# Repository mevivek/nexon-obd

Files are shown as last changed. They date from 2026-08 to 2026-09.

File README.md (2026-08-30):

# Obdurate

> *ob·du·rate* — adj. unyielding; refusing to be moved.

**A read-only black box for your car.** It plugs into the OBD-II port and stays
there. It records every drive to onboard flash whether or not a phone is connected,
prints the sample rate it is actually achieving next to every reading, and never
writes anything to the car — which is a test, not a promise: the build fails if a
write service ever appears in the source.

Built on a **Seeed XIAO ESP32S3**. It hosts its own Wi-Fi access point and serves a
gauge dashboard, on-board monitor results, a UDS identifier scanner and browser-based
OTA updates. No app, no account, no internet, no cloud. Join its Wi-Fi and a page
opens; don't, and it keeps recording anyway.

**Developed and verified against a 2022 Tata Nexon 1.2 petrol (BS6).** The transport
layer, ISO-TP, the recorder, the scanner and the honesty rules are generic. The PID
lists (`PID_B1`–`PID_B4`), the ECU addresses (`ID_ECM_REQ`/`ID_TCM_REQ`), the bus
timing and the warning thresholds are that car's — a different one needs those
changed in the source, and there is no porting guide yet. If you try it on another
car, the measurements are the interesting part; open an issue.

[`docs/FINDINGS.md`](docs/FINDINGS.md) is what was measured on this one, including a
catalogue of the ways a cheap ELM327 clone lies to you.

It reaches the car two ways and picks whichever works:

| Transport | Hardware | Speed | Notes |
|---|---|---|---|
| **BLE ELM327** | none — uses a dual-mode ELM327 already in the OBD port | ~2 Hz | Works today |
| **Direct CAN** | SN65HVD230 transceiver (~₹200) | 50–100 Hz | Preferred once wired |

Everything here was verified against the actual vehicle. Where a claim is untested,
it says so.

---

## Quick start

1. Flash the firmware (see [Building](#building)).
2. Power the board — USB, or from the OBD port via a 12 V→5 V buck.
3. Join Wi-Fi **`Obdurate`** / **`changeme1234`**.
4. Open **`http://192.168.4.1`**.

That is the whole install. The dashboard is compiled into the firmware, so flashing
is all it takes — there is no second step, no laptop at the car, and no state where
the board is running but has no page to show.

You can still deploy a bundle to the filesystem with **`web/deploy.sh`**, and it
takes precedence when present. That is the edit loop: changing a line of CSS costs a
22 KB upload rather than a 1.3 MB reflash. The compiled-in copy is the floor
underneath it, so a failed or half-finished deploy falls back to the last dashboard
that was built into the firmware rather than to a stub.

| Page | What it does |
|---|---|
| `/` | Live gauges — RPM, boost, temps, trims, lambda, catalyst, driver demand |
| `/monitors` | Mode 06 on-board monitor test results, with the ECU's own limits |
| `/scan` | Discover — the autopilot, the sweep, triage and the DID watch |
| `/update` | Upload a new `.bin` over Wi-Fi |
| `/dtc` | Stored + pending fault codes as JSON |
| `/data` | Current sample as JSON, plus firmware version and active transport |
| `/trips` | Per-drive CSV logs — list, download, delete |
| `/history` | The stored trend buffer as JSON |
| `/vehicle` | What this car is and which readings it supports, as JSON |
| `/car` | Which car this board is bound to, and whether it is recording |
| `/auto` | The autopilot's phase and progress |
| `/files` | What data is on the filesystem — the list a backup is built from |
| `/file` | One data file, streamed |
| `/reset` | Erase the data, or the data and the dashboard bundle |

The header shows the running firmware version and which transport is actually live
(`can` or `ble`), so a flashed image can be confirmed at a glance.

A poll can come back with only some of its PIDs — the dashboard reads them in three
batched requests, and one batch can time out while the others answer. When that
happens the affected gauges keep showing their last reading, dimmed, and the header
reports `live · holding N`. After 2.5 s without a fresh value they fall back to `—`
rather than showing stale data indefinitely, and a held reading never raises or
sustains a warning — a value from two seconds ago cannot tell you whether the engine
is still overheating.

A single dropped poll is not reported as a fault either — the status only changes to
`no response from ECU` after five consecutive failures. Dropped replies happen, the
values are held through them, and flipping the status on each one reads as a problem
when nothing is wrong.

### Polling runs on the board, not on the page

The board samples the ECU continuously in `loop()`, one batched request per turn,
and `/data` returns the newest cached sample rather than going to the bus. Polling
therefore does not stop when you close the browser, and no request ever waits for a
poll of its own.

It did, however, wait for *someone else's*. The web server is single threaded, and
until v1.8.0 it got exactly one turn per bus exchange — up to 1.2 s on BLE, twice
that when a batch is retried. A tab switch is three requests (the document, `/time`,
and the new page's first poll), so switching pages could sit behind several seconds
of ELM327 timeouts and felt like a page load rather than a page swap.

Two things fix that, both in `bus_yield.h`:

- **The wait loops serve HTTP.** Waiting on the car is otherwise `delay(1)` on BLE
  and a 5 ms blocking receive on CAN. Both now call `webYield()` instead, which
  serves whatever is queued and reports how long it took — and the response deadline
  moves out by exactly that, because the reply is still waiting behind us either way
  (the TWAI RX queue, or the ELM notify buffer). Without the give-back, serving a
  page would eat the ECU's patience window and surface as a phantom timeout. The
  extension is capped at 3 s so one slow handler cannot hold an exchange open.
- **`loop()` drains the queue** instead of taking one request per turn, so a whole
  page load completes in a single turn.

Two guards keep that safe. `WebServer` tracks a single current client, so
`webYield()` refuses to re-enter it from inside a handler; and `obdIsoTp()` sets a
flag for the duration of an exchange so a handler reached from a yield cannot start
a second one underneath a half-finished reassembly. `/dtc` is the only handler that
touches the bus — it stands down when that flag is set, and because it runs inside
`handleClient()` and therefore cannot yield, its own timeouts are kept short.

The pages help too: the shared ~7 KB stylesheet used to be compiled into all five
documents and re-sent on every switch. It is now served once from `/ui.css` with a
version-stamped, immutable URL, and the pages carry an `ETag` so a re-visit is a
304 with no body. That is also worth ~26 KB of flash.

A sample is published after **every** batch, not after all three. The other two are
carried forward from cache while they are still fresh (3 s), so the page updates at
the bus transaction rate rather than a third of it. Batches are not polled equally
either — `b1` carries everything with a sparkline (rpm, speed, MAP, throttle, load,
coolant) and gets half the turns, because oil temperature and battery voltage do not
move fast enough to deserve equal billing:

| | Refresh |
|---|---|
| `b1` — rpm, speed, MAP, throttle, load, coolant | every 3 batches |
| `b4` — pedal, commanded throttle, torque, absolute load | every 3 batches |
| `b2` — oil, IAT, voltage, trims, fuel rate | every 6 batches |
| `b3` — lambda, catalyst, timing, run time, ambient, fuel | every 6 batches |

A batch that has not answered for three of its own polling cycles is dropped to
`null` rather than published as current, so carrying values forward can never
present a stale number as live. That window is measured, not fixed: `b2` and `b3`
come round once every four batches, so a flat timeout only holds if a batch
completes quickly. Over BLE it does not, and those two batches then expire before
their next turn — blanking twelve of the twenty rows in **All values** on every
cycle. The dashboard's own hold window scales the same way, off the observed sample
interval.

The `[alive]` serial line prints `batch=`, `cycle=` and `stale=` so all three are
visible rather than inferred.

### The board says how fast it is actually reading the car

Those numbers used to go only to the serial log, where nobody sitting in a car can
read them. They are now in `/data` as a `q` block, and on the page as the muted
trailer next to the status pill:

```
live · holding 2      1.87 Hz · b3 6.8 s
```

The rate quoted is **the board's**, not the page's. The page's fetch loop is capped
by its poll interval and throttled harder still in a backgrounded tab, so a rate
measured there can only ever be at or below the one the board is publishing — it
would understate a healthy link and could never catch a sick one. Where the two
genuinely disagree, both are shown, because that is the case worth knowing about:
the log holds samples the screen is not showing you.

This is the number every tool in this category leaves out. An ELM327 round trip puts
a cheap clone somewhere near five PIDs a second; set a tenth-of-a-second logging
interval against that and you get a log that looks complete and is mostly the
previous row repeated, with nothing anywhere to tell you which it is.

Two rules keep it honest, and they are the same ones the readings themselves follow:

- **`hz` is null, not zero, until a full pass has been timed.** A rate of zero is a
  claim that the bus is dead. Not having measured one yet is not that claim, and the
  first second of every drive is spent in that state.
- **A batch that has never answered is null, not a very large age.** Never-answered
  is usually a PID this ECU does not support; long-ago-answered is a link going bad.
  Collapsing them presents the first as the second.

The stalest batch is named only once it is past the board's own derived staleness
window — `b2` and `b3` come round once every four turns by design, so reporting the
worst one unconditionally would be a permanent complaint about nothing.

`/data` also carries a `boot` block: how this run started (`power`, `wake`, `panic`,
`brownout`, `wdt`, …), how long it has been going, and how many deep-sleep wakes
since the last cold boot. A recorder that runs unattended has to be able to answer
*what happened while I was not looking* — a board that has quietly panicked and
restarted forty times otherwise looks exactly like one that has been up all week.

**On BLE, the bus transaction rate is the limit**, and it is mostly round-trip
latency rather than the ECU. The connection interval is the floor: at a default of
40–50 ms a request and its reply cannot beat about a tenth of a second however fast
the car answers. The firmware asks for 7.5–15 ms and a 247-byte MTU, which collapses
a ~80-character reply from four or five notifications into one or two. The adapter
may refuse either, in which case nothing is worse than before. The serial log prints
`batch=NNNms` so the real cost is visible rather than guessed at.

The dashboard stops requesting while the page is off screen, and the Hz readout
counts *published samples* rather than fetches — the same cached sample can be
fetched several times and must not inflate the rate.

### Mileage

Two figures, in the glance area under boost and coolant:

- **Mileage** — the average over this drive, with the totals it came from
  (`23.6 km · 1.66 L`) underneath so the number can be checked rather than trusted.
- **Right now** — instantaneous km/L, which is what the pedal moves. Standing still
  it reads `—` and says `idling` instead, because speed ÷ nothing is not a mileage.

There is no PID for fuel economy, so it is integrated on the board from speed
(`0D`) and fuel rate (`5E`), both confirmed supported on this ECU. On the board and
not on the page, so locking the phone or closing the browser does not lose the drive.
Two rules keep it honest:

- **Both inputs or neither.** Fuel rate lives in the `b2` batch and refreshes half as
  often as speed, so it goes absent regularly. Counting the distance anyway would
  divide real kilometres by an understated litre count and report a mileage better
  than the car achieved.
- **Gaps are not driving.** An interval longer than 5 s — a BLE dropout, a scan taking
  the bus, a wake from sleep — is skipped rather than integrated at the last known
  speed. The clock still moves, so the interval after an outage is one interval, not
  the whole outage.

The average is withheld until roughly the first 0.5 km and 0.1 L. Before that it
swings by tens of km/L between polls and reads as a broken gauge.

Totals start at zero each time the board powers up, which — given the
accessory-socket supply — is exactly one drive. They also go into the trip CSV as
`trip_km` and `trip_l`, so economy over any stretch of a drive can be recovered by
differencing two rows.

One caveat worth knowing: `5E` is the ECU's injection model, not a flow meter. Trip
km/L from it typically reads a few percent optimistic against tank-to-tank. It is
excellent for comparing drives and weaker as an absolute.

### Driver demand vs. delivery

Six of the 55 PIDs the ECM supports trace one chain: **accelerator pedal (`49`/`4A`)
→ commanded throttle (`4C`) → actual throttle (`11`) → demanded torque (`61`) →
delivered torque (`62`)**, with absolute load (`43`) alongside. That is what you
asked the car for, what the ECU decided to do about it, and what the engine actually
produced — which on a small turbo is the interesting part.

Torque is reported as a percentage of the engine's reference torque (`63`), a
constant read once at startup like barometric pressure, so the newton-metre figures
are derived rather than read.

> The scalings are the J1979 ones and have **not been verified against this car** —
> `FINDINGS.md` lists the torque PID scaling as an open question precisely because it
> needs data under load. A wrong data *length* is caught (`mode01Walk` rejects the
> batch), but a wrong *scaling* would not be. Treat the numbers as provisional until
> they have been watched under load and found sane.

### On-board monitors (mode 06)

Mode 06 is the ECU's own test results: what each monitor measured, and the limits it
is judged against. `FINDINGS.md` recorded it as supported (`46 00 C0000001`) and
never explored — so `/monitors` reads it.

The value of it over `/dtc` is that a fault code only appears once a system has
already failed. Mode 06 shows how much room is left, so a catalyst drifting toward
its threshold is visible while it is still passing.

**Pass and headroom do not require knowing the units.** A test passes when its value
sits inside its own limits, and the headroom is a fraction of that window — both
unit-free. The unit-and-scaling table is long and only partly documented, so values
are shown raw with their scaling id, decoded only where the multiplier is
unambiguous. Monitor names likewise: only unambiguous J1979 ids are named, the rest
keep their raw id rather than being given a label that might be wrong.

Discovery walks the support masks (`00` → `20` → `40` …, each mask's last bit
pointing at the next), then each monitor is read one at a time. It runs only while
the page is open — monitors move over minutes, and polling them continuously would
take bus time from the values that move now.

### The DID scan runs in the background

A scan is driven by the board, so it continues if you navigate away, close the
browser, or lock the phone. Only **Stop** — or an OTA upload, which never flashes
mid-scan — ends it.

While it runs the scanner takes most of the bus, but not all of it — the sampler
still gets one batch every two seconds, so live values keep moving slowly rather
than freezing. That costs roughly 15 % of scan throughput, which is a good trade
against a dashboard that is dead for the length of a sweep.

The Live page shows the sweep's progress with counts as well as a percentage — a
full pass is 65,536 requests, so a percentage alone rounds to zero for a long time
and reads as stuck — and the scanner page estimates the time remaining.

Scanning is time-boxed to 250 ms per turn rather than a fixed identifier count. A
count behaves wildly differently per transport — 40 identifiers is about a second on
CAN but roughly 22 s over BLE, during which nothing answers the web server and the
board appears hung.

### Watching identifiers to find out what they hold

A sweep finds identifiers that answer. It cannot say what any of them contain — the
manufacturer-specific block (ISO 14229-1 hands `0100`–`A5FF` to the manufacturer)
comes back as one or two raw bytes with no name, unit or scaling, and that lives in
an ODX database nobody outside the supplier has.

What you can do is correlate. `/watch` reads up to **8** chosen identifiers
continuously and shows them next to rpm, speed, coolant, intake, load and throttle,
each with a sparkline. Blip the throttle and an rpm-linked value gives itself away.
The ones the scanner found are offered as checkboxes, so there is no copying hex
between pages.

**Coming from a build before 1.7.0:** those sweeps kept their hits in RAM only —
nothing was written to flash — so an updated board comes up with an empty picker
even though the sweep happened. The `did_hits.csv` you exported is the only copy,
and the picker loads it directly: choose the file and the identifiers appear as
checkboxes, merged with anything the board found itself. It is parsed in the
browser and kept in `localStorage`; nothing is uploaded, and there is no endpoint
that would make a browser a second source of truth for what the board found.

The same readings become extra columns on the trip CSV — two per identifier: the
bytes decoded big-endian, and the raw bytes beside them. Two bytes might equally be
one 16-bit value or two 8-bit ones and nothing in the reply says which, so the
decode is a convenience and the raw column is the record. An identifier that has
stopped answering writes **empty** cells rather than zeros, the same rule the PID
columns already follow: a missing reading must not correlate as a value of nought.

Changing the set **rotates the CSV**. Columns are fixed when a file is opened, and
shifting them halfway down one is worse than having two files. Re-applying an
identical set is not a change, so pressing Apply twice does not litter the partition.

The cost is real and the page states it. Every watched identifier is one more bus
exchange, and BLE affords about six a second in total — eight at the default one per
second is roughly a sixth of the budget. Watching **pauses entirely while a sweep is
running**; a sweep is already hours long and shares the bus with the sampler, and a
third claimant would do both jobs badly.

This gives correlation, not meaning. It will tell you `1002` tracks coolant; the
offset and scale come from fitting the logged column against the PID afterwards.
Service `0x22` is still a read — only the identifier varies, never the service.

### Trip logs

A CSV row a second while the ECU is answering, written to the 1.5 MB filesystem
partition. Twenty-six columns — wall-clock time and uptime, then twenty-four
readings — and empty cells rather than zeros where a value was not read, so a gap is
a gap and not a reading of nought.

> **This did not work until v1.12.0.** `tripTick()` was written, documented here,
> and never called from anywhere. `/trips/list` returned an empty array on every
> board that has ever run this firmware, and the DID-correlation workflow described
> below — the route this project has for decoding the `10xx` block — has never
> produced a row. If you flashed anything before v1.12.0, there are no trip logs to
> recover; there never were any.

Roughly half a megabyte an hour bare, so the partition holds two to three hours, and
the oldest trip is deleted automatically when space runs short. Watched identifiers
change that materially: each one adds two columns and up to 26 bytes to every row,
so a full set of eight is closer to **1.3 MB an hour — about one hour of capacity**.
The columns are chosen when a file is opened, so the cost is fixed for that file.

LittleFS rather than SPIFFS: the board loses power the instant the ignition goes
off, mid-write as often as not, and LittleFS is built to survive exactly that.

A full partition is the ordinary end state of a device left in a car, not an edge
case. Logging stops rather than pretending: `tripEnsureSpace()` reports whether it
managed to reach the free-space floor, a file is not opened when it did not, and the
row terminator is checked so a write that did not land is seen. Without those, a
failed write left `size()` where it was, the rotation that would have freed space
never fired again, and logging stopped for the rest of the drive in silence.

The clock comes from whichever page you open, so a drive that starts before you open
one has an unset clock for its first rows. Each file's header records whether the
clock was set rather than implying a timestamp it does not have.

### Scans survive being switched off

A sweep is tens of thousands of requests — the better part of a day over BLE — so it
has to outlast the car being switched off. Position goes to NVS as it runs, hits are
appended to the filesystem the moment they are found, and an interrupted sweep
resumes on the next boot rather than starting over.

It also stops sweeping when the ECU stops answering. **A timeout and a negative
response mean opposite things:** a negative response is the ECU saying "no such
identifier", which is a result worth recording; a timeout is no answer at all. After
25 consecutive timeouts the sweep holds its position and probes every few seconds
until the car answers again.

Without that, switching the ignition off mid-sweep would record thousands of
identifiers as "no response" — turning an unswept range into one that looks swept
and empty. That is the same class of silent wrong answer as the `ATCRA` bug in
[FINDINGS](docs/FINDINGS.md), and it matters here because the whole value of the
sweep is its negative result.

### Trend history

The board keeps one hour of RPM, speed, boost and coolant at 6-second resolution and
serves it at `/history`, so the sparklines have shape the moment the page loads
instead of starting flat.

It survives restarts, which matters more than it sounds — the board restarts
constantly in normal use, so history in ordinary RAM would be wiped every time you
got back in the car. How it restarts depends on how it is powered: from the
accessory socket the power is simply cut when the car goes off; from the
permanently-live OBD pin 16 it deep-sleeps after 10 idle minutes and wakes every
30 s, running `setup()` each time.

| Store | Survives | Written |
|---|---|---|
| RTC slow memory (4.8 KB) | deep sleep | every 6 s, free |
| NVS (flash) | power loss | every 6 s (each new sample), and before sleeping |

Which store matters depends on how the board is powered. Wired to the ignition it
simply loses power when the car goes off — RTC memory does not survive that, and the
save on the way into deep sleep never runs, so the periodic flash write is the only
thing keeping a trip's history. It runs on every new sample, so switching off costs
at most 6 seconds. Wired to the permanently-live pin 16 the board deep-sleeps
instead, and RTC memory carries the buffer across for free.

Flushing that often is only affordable because a flush writes **the 400-byte chunk
that moved**, not the whole 4800-byte ring. Rewriting all of it — which is what it
did until v1.3.0 — costs somewhere over a flash sector erase per save, so shortening
the interval that way would have burned through NVS endurance in a couple of years.
Chunked, ten times the flush rate still churns less flash than the old
sixty-second full-buffer write did.

### What car is this

Every other part of this firmware is written against one vehicle. The PID batches
are the set a Nexon replies to, the DID register is 214 verdicts about a Nexon's
ECU, and the dashboard draws tiles for readings that car publishes. Plugged into
anything else, none of that announces itself — the tiles that cannot be filled read
blank, which is indistinguishable from a car that is simply not answering yet.

So the board asks, once per boot: the mode 01 support bitmaps block by block, then
mode 09 for the VIN, the calibration id and its checksum, then one probe at the
transmission's responder id. `/vehicle` reports the answers, including which of the
PIDs the sampler actually polls this car supports.

This is **discovery, not adaptation**. The sampler still asks for the same PID set
and an unsupported reading still comes back absent — it is now labelled
absent-because-unsupported rather than absent-because-silent, which is the whole
difference between a dashboard that is broken and one that is honest. Adapting the
batches at runtime needs a vehicle-profile format, and designing that against a
sample of one car would be designing it blind.

Three states throughout, never two. A support block whose bitmap never arrived reads
*unknown*, not *no*; a mode 09 refusal is a fact about the car, a timeout is a fact
about the last few seconds. Nothing answering at the second responder id is reported
as exactly that, never as "no second ECU" — a module that is not fitted and one that
is not awake produce the same nothing on a CAN bus.

### Backup, restore, and the check in between

A sweep is over half an hour on CAN and the better part of a day over BLE, the
register behind it takes drives to build, and the trip logs are the drives
themselves. All of it lives on a 1.5 MB partition inside a device that gets
unplugged, reflashed and left in a hot car.

The Board page takes the lot off as a ZIP, puts it back, and clears it. The archive
is assembled **in the browser** — the board has one core and a car to poll while it
serves you, so it offers a list (`/files`), a reader (`/file`) and a writer
(`/file/put`) and the page does the work. Entries are STORED, never deflated, so the
file opens with any unzip tool and the reader that puts it back is a header walk
rather than an inflater shipped into a 300 KB budget.

The reason any of this needs the section above: `didmap.csv` is 214 verdicts about
one specific engine and nothing inside it says which. Restored onto a different car
it would not fail — it would attach, silently, and every conclusion drawn from it
afterwards would be about the wrong engine. So a backup carries a manifest holding a
hash of the VIN and calibration id, and a restore compares it. A mismatch is refused
outright with no way past it. A backup or a board with no identity at all is the
ordinary state of a car that has not been driven yet, and that is put to the person
as a question rather than answered on their behalf.

The manifest carries the hash, not the VIN. It answers the only question the archive
is asked exactly as well, and a backup is a file that gets copied to a phone and a
laptop.

### One board, one car

Everything this board accumulates is about a particular vehicle — the sweep's hits
are that car's identifier space, the register is verdicts about that car's ECU, the
trip logs are that car's drives. None of it carries a vehicle in the record itself,
so mixing two cars does not produce a detectable error. It produces a file that is
quietly wrong forever.

So the binding is explicit. The board stores the key of the car it belongs to, and
in a car that is **provably** a different one it records nothing: no sweep, no
triage, no trip log, no correlation. The live dashboard keeps working, because it
reads what the car is doing now and persists none of it — and a board showing a
blank screen in the wrong car would be useless at exactly the moment somebody wants
to glance at a temperature. It also bounds the filesystem, which is the other half
of the reason: a 1.5 MB partition holding one car's data is comfortable and two
cars' is not.

A banner then offers the only choice that is anyone's to make: **onboard this car**,
which erases the previous one's data and starts again, or **keep the other car**,
which leaves the binding alone and gives this one live readings only.

Three answers, not two, and the middle one is the important one. A key exists only
once mode 09 has answered, so "the keys differ" and "there is no key" are completely
different facts and only the first stops anything. Reading absence as a mismatch
would silently disable recording on every car that declines mode 09, and the
symptom — a board that runs, shows live data and never writes a trip log — is one
nobody would diagnose.

### The autopilot

The investigation used to be four phases and three decisions, hours apart, with the
last step done by hand in a spreadsheet. Nobody chooses differently at any of those
points, which is what makes it automatable — and the phases outlast anyone's
attention, so a prompt between them is one that gets missed.

Started once, the board sweeps the identifier space, triages the hits to find which
move, then watches the ones that move eight at a time, fitting each against the live
readings. It advances on its own and keeps its phase in NVS, because the ignition
going off is a power cut and this pipeline is measured in drives:

- **Sweep** — about 30 minutes on CAN, the better part of a day over BLE.
- **Sweep (TCM)** — the same again at the transmission controller, which is a
  separate identifier space at a separate address. Only when discovery's probe at
  0x7E9 actually answered: a sweep of an ECU that is not there does not fail, it
  stalls, and holding position — right for a sweep — would hold the pipeline for
  good. Silence there is reported as "not swept, and here is why", never as proof
  there is no module.
- **Triage** — about an hour of engine-on. This adapter answers roughly half of what
  it is asked, so ten clean reads of every hit needs about twenty passes.
- **Watch** — one drive per eight identifiers, so eight or nine drives for a
  register the size of this car's.

The watch set rotates between drives and never during one: changing it bumps the
watch generation, which rotates the trip CSV, and rotating mid-drive would turn one
drive into a pile of short files.

Two things it will not do. A sweep that finds nothing is a **conclusion** — this ECU
does not answer service 0x22 — not a reason to sweep again. And a car the board is
not bound to **holds** the pipeline rather than ending it, so an afternoon in
somebody else's car does not cost the drives already spent.

### The board does the fitting now

Watching logs an identifier beside rpm and coolant; something then has to fit one
against the other. That was the only step still done by a person, it is the same
arithmetic every time, and it is why a board that had collected everything needed to
answer "what is 1002" still could not say anything about it.

A Pearson correlation is six running sums. Eight watched identifiers against six
reference signals is forty-eight of them, which is nothing on an ESP32, and the best
fit goes into the register as three new columns — so `/didmap.csv` now carries
`tracks,r,samples` on the end. They are appended rather than inserted so a register
written by an older firmware still loads; that file is what a restore puts back, and
a format that rejected last month's backup would throw away hours of bus time to
gain a column.

**It says "tracks", never "is".** Everything under a bonnet correlates with
everything else — oil temperature tracks coolant almost perfectly, and both track
runtime after a cold start — so a strong fit narrows the field rather than settling
it. r is also unchanged by offset and scale, so a perfect correlation still leaves
the units unknown. Naming an identifier stays a human act, which is why
`DID_IDENTIFIED` outranks every machine verdict.

A pair is only counted when **both** sides are present. This adapter drops roughly
half of what it is asked, and folding a missing reply in as a zero would fit the
dropout pattern rather than the car — convincingly.

### Being left in the car

The board deep-sleeps after ten minutes with no ECU response. That timer answers
*the car is off*, which is the ordinary case, and it does not answer *the battery is
going flat* — the two come apart exactly where it matters. An ECU that keeps
answering with the engine stopped (ignition on at the roadside, a long session
parked, a module that stays awake) resets the idle timer on every reply, so the
ten-minute guard never arms and the board keeps drawing from a battery nothing is
charging.

So there is a second floor under it: **below 11.8 V for thirty continuous seconds
with the engine stopped, the board shuts down.** A lead-acid battery at rest sits
near 12.6 V; 11.8 V is roughly a quarter charged and about where a cold start stops
being a certainty.

Three things keep it from firing when it should not, and each is tested:

- **Cranking does not trip it.** The rail sits at nine volts and below for about a
  second while the starter turns, which is the one moment the reading is low and
  switching off would be exactly wrong. Thirty continuous seconds is well past any
  crank, and past the sag from a fan or a heated screen starting up.
- **A turning engine is proof something is charging**, whatever the rail reads, so
  any rpm above 300 breaks the run outright.
- **An absent reading is never a low reading.** An unread voltage and an unknown
  engine state both break the run rather than counting toward it, and the guard is
  fed the sample only while it is fresh — a voltage from ten minutes ago must not
  switch the board off now. That is the idle timer's job and it is already running.

> **The idle draw has not been measured.** The guard above bounds the worst case at
> a battery that can still start the car, but no number for what this board actually
> pulls — asleep, or awake with the AP up — has been put on a meter yet. Until it
> has, treat the advice below about unplugging a parked car as applying to the board
> as much as to the adapter.

The onboard LED encodes state, which matters when the board is hidden under the dash:

- **slow blink (1 Hz)** — alive, Wi-Fi up, ECU not answering
- **fast blink (5 Hz)** — talking to the ECU
- **double-blink** — DID scan running

---

## Frontend

The dashboard is a Preact app under `web/`, built with Vite and served off the
board's filesystem. It is not compiled into the firmware.

```bash
npm --prefix web install
npm --prefix web test          # 206 checks
web/deploy.sh                  # build, then upload to 192.168.4.1
```

**It ships two ways, and the order matters.** The built bundle is compiled into the
firmware, so flashing the board is the whole install. A bundle uploaded to LittleFS
overrides it, which is what keeps the edit loop cheap: changing a line of CSS costs a
27 KB upload, not a 1.3 MB reflash.

That is not a return to what v1.11.0 removed. What went then was hand-written
JavaScript inside C++ raw string literals — no bundler, no packages, no source maps,
and nothing in the build that ever parsed it, so a typo shipped and surfaced as a
dead dashboard in the car. All of that stays gone. `web/scripts/embed.mjs` reads the
output of the ordinary Vite build, after the ordinary Vitest suite, and turns the
finished gzipped bytes into a byte array. Nothing about how the frontend is written,
bundled or tested changes — only where a copy of the result ends up.

What it buys is that there is no state where the board runs and has no page. Someone
who flashes through [`docs/flash/`](docs/flash/) has a working dashboard the moment
it boots, rather than needing a laptop, the board's Wi-Fi and `web/deploy.sh` first.

**Why the board and not a web host.** The access point has no internet, so a phone
joined to it cannot load a page from anywhere else. Chrome 142 relaxed mixed-content
checks for literal private IPs behind a permission prompt, so an HTTPS page *can*
now reach `192.168.4.1` — but only on Chrome, only if the permission was granted
before you got in the car, and Android 17 adds a second prompt on top. Serving from
the board has none of those conditions: no mixed content, no CORS, no permissions, no
internet, any browser.

**Deploying cannot brick it**, and the floor is higher than it was. `/ui` is compiled
into flash, so the page that fixes a bad deploy never depends on the deploy having
worked. If no bundle is installed, or the upload was interrupted, `/` falls back to
the dashboard compiled into the firmware — the whole thing, not a four-value stub.
Trip logging, the DID sweep and the history buffer are the board's work and run
regardless of what the browser can see.

| | |
|---|---|
| Bundle | 27 KB gzipped, **one file**, compiled in and overridable |
| Budget | 300 KB, capped in the build and enforced by the firmware on upload |
| Shares with | trip logs — 300 KB is about 35 minutes of recording capacity |

The build inlines the script and stylesheet into `index.html`, so a deploy is a
single `index.html.gz`. That is not for the bytes — one gzip stream over the lot is
barely smaller than three — but for how it gets installed: the board is updated from
a phone standing next to a car, and a firmware update is one `.bin`, so the frontend
should cost no more than that.

The firmware serves it with `Content-Encoding: gzip` and `no-cache`, so a new deploy
is always picked up, and answers `/monitors`, `/trips`, `/watch` and `/scan` as
redirects into the app's routes so old bookmarks keep working.

**The `/data` contract** is declared in `contract/data.json` and checked from both
ends — the firmware test asserts it against `handleData()` in both directions, so a
field renamed on one side fails the build instead of blanking a gauge on the road.

---

## Hardware

### Option A — no extra parts

Uses a dual-mode ELM327 clone over **BLE GATT**. The ESP32-S3 has **no Bluetooth Classic
radio**, so it cannot use the usual SPP path — but many ELM327 clones also expose a BLE
interface, and this firmware drives that.

Check yours advertises service `FFF0`. On the unit this was built against:

```
BLE address 81:23:45:67:89:BA   name "OBDBLE"
  SERVICE 0000fff0
    CHAR 0000fff1  Read, Notify               <- responses
    CHAR 0000fff2  WriteWithoutResponse, Write <- commands
```

Note the BLE address is the Classic MAC with the top bit of octet 0 set
(`01:…` → `81:…`). Set `ELM_BLE_ADDR` in `elm_ble.h` to match your adapter.

### Option B — direct CAN (recommended)

| Part | Notes |
|---|---|
| **SN65HVD230** transceiver | **3.3 V part.** Do *not* use TJA1050 or MCP2551 — they are 5 V logic and will damage the ESP32's RX pin |
| 12 V→5 V buck (MP1584/LM2596) | Set output to 5 V *before* connecting the board |
| OBD-II male pigtail | |

**Wiring**

| XIAO ESP32S3 | SN65HVD230 |
|---|---|
| D1 (GPIO2) | CTX / D |
| D2 (GPIO3) | CRX / R |
| 3V3 | VCC |
| GND | GND |

| SN65HVD230 | OBD-II pin |
|---|---|
| CANH | 6 |
| CANL | 14 |

Power from OBD pin 16 (+12 V) and pin 4/5 (GND) into the buck, 5 V out to the XIAO's `5V` pad.

> **Remove the 120 Ω termination resistor** on the transceiver breakout. The vehicle bus
> is already terminated at both ends; a third terminator causes bus errors.

> **OBD pin 16 is permanently live**, so anything plugged into the OBD port draws
> from the battery whether the car is running or not. That includes a BLE ELM327
> adapter — clones typically pull 20–50 mA, roughly 0.5–1 Ah a day — so unplug the
> adapter if the car is parked for more than a few days. This applies to the adapter
> even when the board itself is powered from the accessory socket and switches off
> with the ignition; the two are independent.
>
> The board deep-sleeps after 10 minutes with no ECU response, which protects the
> battery only if the board is itself wired to a permanently-live supply.

---

## Building

```bash
firmware/build.sh              # tests, then compile
firmware/build.sh --upload     # …then flash over USB (PORT=… to pick the port)
```

If you already have `arduino-cli` with the ESP32 core — an Arduino IDE install counts
— it uses that and downloads nothing. Only on a machine with neither does it install a
private copy into `firmware/.toolchain/` (~6 GB unpacked, several minutes), and that
install writes nothing outside the repo, so deleting the directory undoes it
completely. `OBDURATE_ISOLATED=1` forces the private toolchain, which is what CI
wants: a build that depends on whatever happens to be on the machine is not
reproducible.

The upload port is guessed from `arduino-cli board list`, taking only a port it
recognises as an ESP32 — Windows has several Bluetooth serial ports that must not be
flashed at. Override with `PORT=COM3` or `PORT=/dev/ttyACM0`.

> Building needs `g++`, `python3` and `node` on `PATH` for the host tests, which run
> before the compile. Contributor notes for the development machine — including where
> its compiler lives and how to read the board's serial log on Windows — are in
> [`CLAUDE.md`](CLAUDE.md).

The output you want is **`firmware/build/Obdurate-v<version>.bin`** — the app image,
which is what `/update` takes. The version comes from
[`firmware/Obdurate/version.h`](firmware/Obdurate/version.h); bump it there and the
filename, the dashboard header and the serial banner all follow.
`Obdurate.ino.merged.bin` in the same directory is a full-flash image for USB
recovery; feeding *that* to `/update` will not work.

By hand, if you would rather not use the script:

```bash
arduino-cli config add board_manager.additional_urls \
  https://espressif.github.io/arduino-esp32/package_esp32_index.json
arduino-cli core update-index
arduino-cli core install esp32:esp32

arduino-cli compile --fqbn esp32:esp32:XIAO_ESP32S3 --output-dir build firmware/Obdurate
arduino-cli upload -p COM3 --fqbn esp32:esp32:XIAO_ESP32S3 firmware/Obdurate
```

Current size: **1.26 MB flash (37 % of `app0`)**, 49 KB RAM (15 %), plus 4.8 KB of
RTC slow memory for the trend buffer. The frontend is no longer part of that: it is
a 22 KB gzipped bundle on the filesystem, and moving it out returned 47 KB of flash.

The default `default_8MB` partition already provides `ota_0` + `ota_1` at 3.19 MB each,
so OTA works without changing the partition scheme.

### Tests

```bash
firmware/test/run.sh          # needs g++, python3 and node — no ESP32 core, no board
```

The ISO-TP layer and the mode-01 batch poller are extracted straight out of
`Obdurate.ino` and compiled against fake TWAI and ELM327 shims, so frame sequences
that are impractical to stage against a real car — a dropped consecutive frame, a
reordered sequence number, a reply that stops halfway — are covered. The same shims
stand in for the web server, so the deadline give-back described above is tested for
the two properties that make it safe: a silent ECU is still reported silent, and the
extension is bounded. Everything else the sketch
can be asked about without a board — the `/data` contract, the routing, the caching
headers, the DID watch wiring, the trip columns, the history constants — is asserted
against the source under node.

The frontend has its own suite, `npm --prefix web test`: 382 checks over the
hold-last-value merge, the warning-flag gating, the rate tracker, the mileage
readouts and each page's logic, run against the modules that implement them. That is
the point of the split — those used to be JavaScript inside C++ raw string literals,
which nothing in the build ever parsed, so a typo shipped and surfaced as a dead
dashboard in the car.

The "All values" table is checked in a real browser instead, because the node
harness structurally cannot check it: its fake DOM creates any element asked for by
id, so a table whose cells are built once and then addressed by id passes whether or
not those ids line up with the rows — the whole suite goes green with every value
shown against the wrong PID. `test_table.mjs` renders the built bundle and
the built bundle, drives it through a full sample, a partial poll and a recovery,
and asserts that row *i* shows the value of the PID row *i* names. It skips itself, without failing, where
Playwright is not installed.

To look at the pages without flashing anything:

```bash
node firmware/test/shots.mjs out/     # needs playwright + chromium
```

It serves the real pages against a mock `/data` and screenshots them at phone and
tablet widths across four states — cruising, a partial poll, warnings, and ignition
off. The partial-poll shot is the one worth checking after any change to the polling
code, since that is the state that used to blank the dashboard.

### OTA

Run `firmware/build.sh`, join `Obdurate`, and upload
`firmware/build/Obdurate-v<version>.bin` at `http://192.168.4.1/update`. The header
shows the new version once it reboots, which is how you confirm the flash took.

The board runs from `app0`; an upload streams into `app1`; `otadata` only flips once
`Update.end()` verifies the image, then it reboots. An interrupted or corrupt upload never
touches `otadata`, so **a failed OTA cannot brick the board** — it reboots into the
firmware it was already running.

So the loop is: build locally → copy the `.bin` to your phone → join the board's Wi-Fi →
upload at `/update`. No dev machine needed at the car, only to produce the image.

> **CI is not in use.** [`ci/build.yml`](ci/build.yml) is kept current — it runs the host
> tests and compiles the firmware — but it is parked outside `.github/workflows/`, since
> pushing there needs the `workflow` OAuth scope this repo's token lacks. Build locally
> with `firmware/build.sh`. To enable CI later:
>
> ```bash
> gh auth refresh -h github.com -s workflow
> git mv ci/build.yml .github/workflows/build.yml
> git commit -m "Enable CI" && git push
> ```

---

## Before you use this

Change the access point credentials in `Obdurate.ino` — they are placeholders, and the
board is an open target on any network it creates:

```cpp
static const char *AP_SSID = "Obdurate";
static const char *AP_PASS = "changeme1234";   // >= 8 chars
```

`/update` has **no authentication**. Anyone who can join the AP can flash the board, so a
strong `AP_PASS` is the only thing protecting it.

Set `ELM_BLE_ADDR` in `elm_ble.h` to your own adapter's BLE address — the one committed
here is from the unit this was developed against.

---

## Architecture

```
                    ┌───────────────────────────┐
  phone ──Wi-Fi AP──┤  XIAO ESP32S3             │
                    │   WebServer :80           │
                    │   bundle (LittleFS) + API │
                    │                           │
                    │   obdIsoTp() dispatcher   │
                    │      ├── canIsoTp  (TWAI) ├──SN65HVD230──┐
                    │      └── bleIsoTp  (GATT) ├──BLE──ELM327─┤ OBD-II
                    └───────────────────────────┘              │  pins 6/14
                                                               ▼
                                                            vehicle CAN
```

Both transports implement the same contract — request bytes in, reassembled ISO-TP
payload out — so mode 01, mode 03 and UDS `0x22` are written once and work on either.

`chooseTransport()` prefers CAN when the transceiver answers, else falls back to BLE.
While the ECU is silent it re-evaluates on a backoff — 2 s, then 4, 8, 16, settling
at 20 — resetting to impatient as soon as data arrives.

That matters when the adapter outlives the board, which is the usual split: the OBD
port is always live but an accessory-socket supply is not. Every start then meets an
ELM327 that may still be holding the BLE link to a board that vanished without
disconnecting, so the first connect can fail for a reason that clears itself within
seconds. A flat retry interval meant a dead dashboard for that whole interval at
every ignition.

---

## Safety

This firmware is **read-only by design**, and since v1.12.0 that is a test rather
than a promise. Every request buffer in the sketch is found from its call sites, its
service byte read out of the source, and checked against the list of reads. Adding a
write service fails the build and names it.

What it actually sends, as the check reports it:

| Service | |
|---|---|
| `0x01` | mode 01 live data |
| `0x03` | mode 03 stored fault codes |
| `0x06` | mode 06 on-board monitor results |
| `0x22` | UDS ReadDataByIdentifier |

plus ISO-TP flow control. It never sends:

| Service | Why not |
|---|---|
| `0x2E` WriteDataByIdentifier | writes ECU memory |
| `0x31` RoutineControl | triggers actuators |
| `0x11` ECUReset | resets a live ECU |
| `0x10` DiagnosticSessionControl | changes ECU state |
| `0x27` SecurityAccess | unlocks protected functions |
| `0x14` ClearDiagnosticInformation | erases the car's own record |

> This table used to claim mode 07 (pending codes) and mode 09 (vehicle info) as
> well. Neither is sent — there is no `0x07` or `0x09` request anywhere in the
> sketch, and the sketch's own header comment made the same claim. Writing the check
> is what found it. Both are reads and both are worth having; they are simply not
> implemented yet.

A request is also bounded now. An ISO-TP single frame is one PCI byte and seven of
payload, and the request was copied into an eight-byte stack buffer with nothing
checking the length. The largest caller in the tree — the mode 01 batch, six PIDs
plus the mode byte — passes exactly seven. At the limit, with nothing spare: a
seventh PID in a batch, or packing two identifiers into one `0x22` request to get
the obvious threefold throughput win, would have written past the frame and said
nothing about it.

Run scans **parked**. Reading is safe; a stalled request while driving is not worth the risk.

---

## Documentation

- **[docs/FINDINGS.md](docs/FINDINGS.md)** — what this specific car exposes, and the
  adapter quirks that cost hours to discover
- **[docs/TOOLS.md](docs/TOOLS.md)** — the PowerShell scripts in `tools/`

## Licence

MIT — see [LICENSE](LICENSE).

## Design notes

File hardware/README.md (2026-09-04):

# Obdurate Rev A — hardware

One carrier board, 40 × 40 mm, four layers, in a clear Minitools case whose
OBD-II connector is a matched module from the same family. It carries the CAN
transceiver, the 12 V power chain and the test points; the MCU arrives as a
module, and there are **two variants of which module**.

**There is no schematic or layout here yet, and no Gerbers.** What is here is
everything a schematic would carry, in formats that can be checked: the netlist,
the placement, the board outline, the bill of materials and the fab settings.

Everything is a *design*, not a *measurement*. Nothing has been fabricated. The
prototype that proved the firmware is a XIAO ESP32S3 on flying leads to an
SN65HVD230 breakout — which is exactly what the `-xiao` variant turns into a board.

---

## Two variants, one circuit

| | `-xiao` | `-wroom` |
|---|---|---|
| Module | Seeed XIAO ESP32S3, 21 × 17.5 mm | ESP32-S3-WROOM-1-N8R8, 18 × 25.5 mm |
| Buck output | **5 V** into the XIAO's 5V pad; its LDO makes 3.3 V | **3.3 V** directly |
| USB | on the module | J2 on the board, **0.5 mm pitch** |
| 3.3 V regulator | on the module | U4 + D3 OR diode on the board |
| Status LED | **on the module** — its onboard LED *is* GPIO21 | LED1 + R1 on the board |
| Boot / reset | buttons on the module | R3, R4, C7 on the board |
| Antenna | U.FL flying part, positioned in the case | PCB antenna, needs a board keepout |
| Finest pitch | 1.27 mm (SOIC-8) | 0.5 mm (USB-C) |
| Parts | ~25 | ~38 |
| Module cost | ~$7.00 | $3.20 |

**Rev A is `-xiao`.** Rev A's job is Gate 1 — five units surviving a week in a
car — not hitting a cost target, and the XIAO removes twelve parts, the finest
pitch on the board, the antenna keepout and two open questions. It is also what
the firmware already runs on, so nothing about the software is new.

**`-wroom` is the volume answer.** Roughly $2.70 a unit cheaper once the twelve
parts it adds back are counted, more integrated, and it looks like a product
rather than a dev board on a carrier — which matters behind a clear case at $119.
Move to it for Rev B if the volume justifies the extra layout.

The shared 90% is written once. Every CSV carries a `variant` column of `common`,
`xiao` or `wroom`, and the effective design is the common rows plus one variant's.
Both are checked independently by the build, because a shared circuit with one
checked half has an unchecked half.

## Files

| | |
|---|---|
| [`netlist.csv`](netlist.csv) | Every net and its member pins, per variant. **Checked against the firmware** |
| [`placement.csv`](placement.csv) | X/Y/rotation for every part, board-local mm, with the reason it sits there |
| [`bom.csv`](bom.csv) | Per-variant, each line tagged `spec`, `class` or `estimate`, each with a KiCad footprint |
| [`xiao-pinmap.csv`](xiao-pinmap.csv) | XIAO pad → GPIO, with a source and a confirmed/unverified flag per row |
| [`outline.dxf`](outline.dxf) | 40 × 40 mm, 2 mm corner radii, mm units. Import as `Edge.Cuts` |
| [`fab.md`](fab.md) | What to select when ordering, and why |

`spec` means a real part number whose datasheet outline is settled. `class` means
the envelope is right and the SKU is still open. Same convention the project's
README uses for measurements: an unverified claim says so.

## The build checks this against the firmware

| Net | `-xiao` | `-wroom` | Firmware |
|---|---|---|---|
| `CTX` | `U3.D1` | `U3.IO2` | `PIN_CAN_TX = GPIO_NUM_2` |
| `CRX` | `U3.D2` | `U3.IO3` | `PIN_CAN_RX = GPIO_NUM_3` |
| LED | *none — the module's* | `LED_K` → `U3.IO21` | `LED_PIN`, **active low** |

`firmware/test/hardware.mjs` reads the pin number out of the sketch and checks
the netlist against **that**, translating through `xiao-pinmap.csv` on the XIAO
variant where the pad is called `D1` rather than `IO2`. Asserting "the netlist
says IO2" and "the firmware says GPIO2" as two independent facts would pass
happily after someone changed both to different values.

The bus is **500 kbit** ISO 15765-4, CAN 11-bit — what the firmware configures,
and what picks both the transceiver and the common-mode choke. The build checks
that number against the sketch too.

Two things this catches that are easy to get wrong. The LED is driven **active
low**, so on `-wroom` its anode sits on the rail through R1; flip the firmware and
that board is wrong in a way reflashing cannot fix. And on `-xiao` there must be
**no** board LED, because GPIO21 is not on a XIAO pad at all — it is the module's
own onboard LED, which is what `LED_BUILTIN 21` has always referred to. Adding one
would put two things on one pin.

## Two rules decided the layout

1. **The 12 V chain owns the left half and never crosses the CAN pair.** Power
   enters front-left and stays there; CAN H and CAN L enter front-right and reach
   U1 in about 9 mm. The switching node between U2 and L1 is the shortest, widest
   trace on the board. This is also what makes the board routable without
   crossings.
2. **The module sits at the rear with nothing underneath it.** The common parts
   are positioned to clear *both* module footprints, so the power and CAN sections
   do not move between variants.

The case picked the board size: every end cap and connector in the Minitools
modular OBD family is a **43 × 21 mm module**, so that interface is the hard
constraint and the board can be at most about 41 mm across.

## Open questions

Unresolved, not overlooked.

- **Does the case ship in clear polycarbonate at this size?** The PC variants
  verifiable in stock listings are the narrower `-N-PC` and `-L-PC` boxes, not the
  48 mm-wide `-M` this board needs. The answer changes the outline, so it comes
  before the layout.
### Answered

- **Is the XIAO's 5V pad diode-isolated from VBUS? No — it is not.** Seeed's own
  expansion-board guidance is explicit that an external supply into the 5V pad
  needs a series Schottky, anode to the supply. Without it, plugging USB in
  back-powers whatever is feeding that pad. **D5 exists because of this**, and it
  is not optional. It costs ~0.3 V, leaving ~4.7 V into the module, which its
  regulator handles comfortably.
- **Does the XIAO's regulator have headroom for U1's ~70 mA?** Not published for
  the S3. The C3's 3V3 pad is rated 700 mA and the S3 schematic names the part
  `SGM6029CYG`, but I will not plan against a rating I cannot source. Resolved by
  design instead: **R13** links the module's 3V3 to U1 on Rev A, and **U5** is an
  unpopulated local LDO on the same net. Fit one or the other, never both. Then
  measure it in Phase 1, which is already the first hardware action. An
  unpopulated footprint costs nothing next to a board spin.
- **GPIO3 is an ESP32-S3 strapping pin** (JTAG source select), driven here by
  U1's receive output, which idles high because recessive is the bus's resting
  state. Almost certainly fine, and exactly the kind of "almost certainly" that
  costs a board spin. Affects both variants.
- **L1's value** is 33–47 µH pending the LM5164 application circuit, and its
  height sets the minimum internal clearance — the part most likely to force the
  case taller.
- **R10/R11 and R12 values** — the feedback divider ratio differs by variant
  because the output does, and R12 sets the switching frequency. Both come off the
  datasheet.
- **`-wroom` only: the USB-only rail sits near 3.05 V** after D3's drop, just
  inside the ESP32-S3's 3.0–3.6 V range. Matters for bench flashing with no car
  attached; a power-mux IC is the better answer than a bigger diode.
- **Most of `xiao-pinmap.csv` is `unverified`** — the pad order comes from the
  XIAO form factor, and only D1, D2, 3V3 and GND are corroborated by this repo.
  Getting it wrong swaps pins, so check it against Seeed's own footprint before
  sending Gerbers.

## Building the board

[`build_board.py`](build_board.py) turns these CSVs into a real `.kicad_pcb`:
footprints loaded from the stock libraries, placed per `placement.csv`, nets
assigned per `netlist.csv`, and the 40 × 40 mm outline drawn on `Edge.Cuts`. Run
it with KiCad's own Python, which is the one that has `pcbnew`:

```
"%LOCALAPPDATA%\Programs\KiCad\10.0\bin\python.exe" build_board.py xiao wroom
```

Current state — both variants build with **every pad resolved**:

| | `-xiao` | `-wroom` |
|---|---|---|
| Footprints placed | 36 | 46 |
| Pads connected | 83 | 137 |
| Nets | 23 | 30 |
| Unresolved | 0 | 0 |
| Copper past the outline | none | none |

The script holds no design data of its own except the **pin name → pad number**
maps, which cannot live in the CSVs: the CSVs name pins, footprints number pads.
Those maps come from KiCad's own symbol libraries, read out by `pinout.py`, plus
`xiao-pinmap.csv` for the XIAO row order and the USB-C Type-C contact
designations for J2.

Then to look at it or export it:

```
kicad-cli pcb export glb    --output revA-xiao.glb obdurate-revA-xiao.kicad_pcb
kicad-cli pcb render        --output iso.png --quality high --perspective \
                            --zoom 0.75 --rotate "-32,0,22" obdurate-revA-xiao.kicad_pcb
kicad-cli pcb export gerbers --output gerbers/ obdurate-revA-xiao.kicad_pcb
```

GLB and PNG outputs are gitignored — they regenerate in about a second and a
quarter respectively, and there is no reason to carry megabytes of binary that a
command reproduces.

**Two things the render exposed that nothing else would have.** Stock footprints
ship their 3D models with `(hide yes)`, so the first render came out as bare pads
with no parts on it at all. And KiCad ships **no 3D model for any XIAO board** —
`MCU_Seeed_ESP32C3.step` is referenced but absent — so the `-xiao` render shows
the land pattern with nothing standing on it. The WROOM's model does exist.

**What still needs doing:** the silkscreen designators collide in the power
section, which is cosmetic but ugly and worth fixing before Gerbers. Netclasses,
the ground pour and the `-wroom` keepout zone are not created yet. And nothing is
routed — the board has a correct netlist and a ratsnest, which is the input to
routing rather than its output.

## Getting from here to Gerbers

1. Netclasses per `netlist.csv`, ground pour on an inner layer, keepout on `-wroom`.
2. Route. The layout was designed so the nets do not need to cross.
3. DRC, then `kicad-cli pcb export gerbers`.

DRC checks geometry, not whether the circuit is right. The netlist is checked
against the firmware for the CAN pins and the LED, and against itself for
completeness — but nothing checks that R8/R9 are on the correct side of U2's
EN/UVLO pin. That comes off the datasheet, which is why U2's pins are named here
rather than numbered.

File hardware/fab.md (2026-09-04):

# Ordering Rev A

**Order the `-xiao` variant.** Same board outline and the same fab settings as
`-wroom`, so everything below applies to either — but the XIAO variant's finest
pitch is 1.27 mm rather than 0.5 mm, which is the difference between a board you
can hand-assemble with hot air and one you would rather not.

Fabrication only — none of these vendors' PCB pages include assembly. Bare
boards cover the ~$0.60 PCB line in the plan's BOM, not the ~$2.60 assembly
line. Five `-xiao` prototypes are genuinely hand-solderable: SOIC-8, 0603, 1210
and a castellated module are all within reach of hot air, and the XIAO removes
the USB-C, the LDO and the LED from the job. For 300 units you need turnkey PCBA
with component sourcing, and [`bom.csv`](bom.csv) is the file they will ask for —
filter it to `common` plus the variant you are building.

## Quantity

**Order 5, not 1–2.** Robu's minimum is 5 anyway, and 5 is the right number
regardless: hand-assembling a first four-layer board with a castellated module
teaches you something, and what it teaches you may cost you that board. You want
one you are willing to destroy. Gate 1 in the plan is *five units surviving a
week in a car* — one working board says the design can work, five say it
reliably does, and only the second claim justifies taking anyone's money.

Bare boards are the cheapest line in the whole BOM. Ordering two to save money
is a false economy when the parts and your evenings dominate.

**For the first spin, send the same Gerbers to two fabs.** For a few hundred
rupees you learn who gives real DFM feedback, whose silkscreen holds 1.2 mm
text, and whose quoted lead time is honest. At this stage that is worth more
than the boards.

## Settings

Taken from Robu's order form. The reasoning generalises to any fab.

| Setting | Choose | Why |
|---|---|---|
| Layers | **4** | Ground plane plus routing |
| Dimensions | **40 × 40 mm** | Set by the case's 43 × 21 mm cap interface |
| Quantity | **5** | See above |
| Product type | Industrial / consumer | Not aerospace or medical |
| Thickness | **1.6 mm** | The case rails assume it |
| Delivery format | **Single PCB** for protos, **panel** for production | Assembly houses want rails and fiducials; hand-building five does not |
| Material | **S1141 TG140** or **S1000H TG155** | Not the default TG135. This lives in a footwell through an Indian summer — higher glass-transition temperature is cheap margin |
| Colour | Green for protos | Behind a clear case this becomes a product decision, not an internal one. Black with white silkscreen reads better in the box |
| Silkscreen | White | |
| Surface finish | **ENIG-RoHS** | Three reasons, below |
| Copper weight | 1 oz | Peak draw is ~0.5 A. 2 oz buys nothing |
| Via covering | Tented | Keeps solder off the ground-stitching vias |
| Remove order number | **Yes** | Through clear polycarbonate the fab's order number is a visible blemish |
| Electrical test | Flying probe, full | Take it |
| Appearance quality | IPC Class 2 | Class 3 is for high-reliability hardware. This is a read-only diagnostic accessory, not a safety system |
| Gold fingers / castellated / edge plating | No | The castellations belong to U3, which is a bought part |

### Why ENIG is worth the upcharge

1. The six pogo test pads need a flat, oxidation-resistant surface to make
   reliable contact across 300 units. HASL's uneven blobs are the wrong surface
   for a probe to land on, and the plan commits to testing every unit.
2. The board is visible through a clear case.
3. **HASL with lead is not RoHS compliant**, which forecloses the EU and UK
   entirely — and it is the option preselected by default on that form.

## Design rules to route to

| | |
|---|---|
| Minimum via | 0.30 mm drill / 0.60 mm pad |
| Board outline tolerance | ±0.2 mm — comfortable against 1.5 mm case clearance per side |
| Minimum silkscreen text | **1.2 mm.** The concept model used 1.05 mm for `TP1`–`TP6`, which is at the fab floor — raise it before exporting |
| Minimum trace / clearance | 0.15 mm is available; nothing here needs finer than 0.25 mm |
| Finest pitch on the board | **`-xiao`: 1.27 mm** at U1/U2's SOIC-8. `-wroom`: 0.5 mm at J2's USB-C, which is what would set that variant's fab class |
| Copper | 1 oz outer |

## Lead time

Robu quotes **15–20 business days**, which is three to four weeks and slower
than a Chinese fab direct — the price and the wait both include import into
India. Budget for it: at that cadence a rev A → rev B loop is two months, which
is most of Phase 1.

## The one thing that changes the plan

If the boards are fabbed *and* assembled in India and exported to Crowd Supply's
warehouse, that is a plain **export of goods** — an IEC plus an LUT for
zero-rated GST — rather than the merchanting-trade transaction the plan assumes
when manufacturing in Shenzhen and shipping straight to Portland. Probably a
higher unit cost, definitely simpler paperwork, and merchanting trade is the
fiddliest item in the plan's compliance section.

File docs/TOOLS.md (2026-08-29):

# Laptop tools

> The standalone laptop dashboard (`tools/dashboard.html`, served by
> `obd_dashboard.ps1`) has been retired. It was a second implementation of the
> gauges, with its own copy of the merge, hold and warning logic and its own test
> suite, kept in step with the board's by hand - and the board now ships that
> dashboard compiled into its own firmware, reachable from any phone without a
> laptop in the car at all. Two implementations of one screen is a maintenance
> cost with nothing on the other side of it.
>
> The scripts below are exploration tools, not a dashboard, and they stay: they
> answer questions about a car that the board is not the right shape to ask.

PowerShell scripts that drive an ELM327 over **Bluetooth Classic SPP** from Windows. These
predate the ESP32 firmware and remain useful for bench work — they need no extra hardware
beyond the adapter, and they were how every finding in [FINDINGS.md](FINDINGS.md) was made.

They use `System.IO.Ports.SerialPort` only, so **nothing needs installing** — no Python,
no `pyserial`.

## Pairing the adapter

The adapter pairs as a standard Bluetooth device with PIN `1234`, appearing as an outgoing
COM port. Windows PowerShell cannot subscribe to WinRT events, so scripted pairing needs a
small compiled helper; pairing through Windows Settings is simpler and equivalent.

Confirm the port with:

```powershell
[System.IO.Ports.SerialPort]::GetPortNames()
Get-PnpDevice -Class Ports | Where-Object FriendlyName -match 'Bluetooth'
```

All scripts assume **COM5**. Change the literal at the top of each if yours differs.

---

## `obd_enum2.ps1`

Header-aware enumeration of everything the car exposes: supported-PID walk per ECU, live
values with decoded units, mode 03/07 fault codes, and mode 09 vehicle info.

Uses `ATH1` and demultiplexes by responder ID, because `ATCRA` filtering does not work on
this adapter — see FINDINGS. An earlier version that trusted `ATCRA` silently reported the
transmission's PID list as the engine's.

## `uds_ecm_sweep.ps1`

Brute-forces UDS service `0x22` across selected ranges on the ECM, printing every DID that
returns a positive `0x62` response and exporting `ecm_did_hits.csv`.

Read-only: service `0x22` only. Never sends `0x2E`, `0x31`, `0x11`, `0x10` or `0x27`.

Timing is the tricky part — `ATST` too short truncates `responsePending` (`0x78`) replies and
silently loses DIDs; too long makes a full sweep take hours. Run it **parked**.

## `obd_capability.ps1`

Answers "would better hardware help?" empirically:

1. Monitors the bus passively (`ATMA`) to see whether any free-running CAN traffic exists.
2. Probes UDS `0x22` with standard ISO 14229 identification DIDs.
3. Checks which standard modes respond at all.

On this car, test 1 captures nothing — which is how the gateway isolation was established,
and why a CAN sniffer at the OBD port is not worth buying.

---

## Output files (gitignored)

`obd_log.csv`, `did_hits.csv` and `ecm_did_hits.csv` contain the **VIN** (`0902`, `22 F190`,
`22 F1A0` all return it). They are excluded from version control deliberately — keep them
off GitHub, forums and issue trackers.

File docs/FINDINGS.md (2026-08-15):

# Findings — 2022 Tata Nexon 1.2 petrol (BS6)

Everything here was measured against the car, not taken from a datasheet. Dates: August 2026.

> No VIN, registration or other identifying data is committed to this repo. The scan tools
> write CSVs containing the VIN (`0902`, `22 F190`, `22 F1A0`) — those files are gitignored.

---

## Bus and modules

| | |
|---|---|
| Protocol | ISO 15765-4, CAN 11-bit, 500 kbit |
| ECM | request `7E0` / response `7E8` — supplier **`BOSCH LIMITED`** (`22 F18A`) |
| TCM | request `7E1` / response `7E9` — **`TCM-TransmisCtrl`** (AMT) |

### The OBD port is gateway-isolated

`ATMA` (monitor all) captures **zero frames** over 8 seconds. There is no free-running
broadcast traffic on pins 6/14 — only diagnostic request/response passes the gateway.

**Consequence:** a CAN sniffer at the OBD connector records nothing. SavvyCAN, cabana and
similar reverse-engineering workflows are useless here without tapping a bus behind the
gateway. Only polling works.

---

## Adapter quirks (ELM327 v1.5 clone)

These cost hours. All reproducible.

### `ATSP0` auto-detect fails

Auto-detect identifies the protocol correctly (`ATDP` reports `AUTO, ISO 15765-4 (CAN 11/500)`)
but every request returns `NO DATA`. Forcing the protocol works first time:

```
ATSP6      # CAN 11-bit 500k
ATAT2      # adaptive timing, aggressive
ATST 64    # 100 x 4 ms = 400 ms
```

### `ATST` must be shorter than the reader's own timeout

`ATST` is how long the *adapter* waits for the ECU, and it has to be comfortably
below however long the host waits for the adapter. Set the other way round — `ATST FF`
is 255 × 4 ms = 1020 ms — the host gives up first and reads a buffer with no `>`
prompt, which is a truncated reply by definition. Every such reply is then lost, even
though the ECU answered perfectly well a moment later.

On the firmware's BLE transport this showed up as a dashboard that was almost
entirely blank at **0.3 Hz**: a 900 ms read window against a 1020 ms adapter timeout,
so slow replies were cut off, discarded, and retried until the poll rate collapsed.
`ATST 64` (400 ms) against a 1200 ms read window leaves the adapter room to answer —
even if the answer is `NO DATA` — before the host stops listening.

### `ATCRA` does not filter

The receive-address filter is accepted but does nothing — replies from **both** ECUs come
back regardless. Parsing the first `41xx` in the buffer therefore reads whichever ECU
answered first.

This produced a real, silent error: the ECM's supported-PID mask was read as `88188001`
(the TCM's) instead of `FE3EA813`, reporting 11 PIDs where the ECM actually has 55.

**Fix:** enable headers (`ATH1`) and demultiplex by responder ID in software. This firmware
does that on both transports.

### The BLE interface exists, on a different address

The adapter is **dual-mode**. Its BLE address is the Classic MAC with the top bit of octet 0
set — `01:23:45:67:89:BA` → `81:23:45:67:89:BA` — and advertises as `OBDBLE`:

```
SERVICE 0000fff0
  CHAR 0000fff1  Read, Notify                <- responses
  CHAR 0000fff2  WriteWithoutResponse, Write <- commands
```

A passive scan filtered on the Classic MAC finds nothing and looks like proof there is no
BLE. An **active** scan capturing service UUIDs finds it immediately. This matters because
the ESP32-S3 has no Bluetooth Classic radio and BLE is its only route to the adapter.

### Bluetooth Classic SPP link drops when idle

`SerialPort.Open()` then throws *"The semaphore timeout period has expired"*. Retry-on-open
is mandatory; a single attempt will silently fail and every subsequent command returns
nothing while appearing to run.

### Batched PID requests are ~4× faster

Mode 01 accepts up to 6 PIDs in one message. Measured on this car:

| | |
|---|---|
| 6 separate requests | 672 ms |
| 1 batched request | **171 ms** |

---

## What the car exposes

### Mode 01 — ECM: 55 PIDs

```
01 02 03 04 05 06 07 0B 0C 0D 0E 0F 11 13 15 1C 1F 20 21 2E 2F 30 31 33 34 3C
40 41 42 43 44 45 46 47 49 4A 4C 4D 4E 4F 50 51 56 5A 5C 5E 60 61 62 63 67 70
80 87 9E
```

Notable: `70` boost pressure control, `3C` catalyst temp B1S1, `34` wide-range lambda,
`61`/`62`/`63` torque, `5C` oil temperature, `5E` fuel rate.

**`10` (MAF) is not supported** — this ECU is speed-density, so airflow derives from MAP (`0B`).

### Mode 01 — TCM: 11 PIDs

`01 05 0C 0D 11 20 21 30 31 40 42` — generic mirrors only. **No gear position, clutch state
or ATF temperature** over standard OBD.

### Values that are present but not trustworthy

| PID | Reads | Reality |
|---|---|---|
| `2F` fuel level | pegged 100.0 % | not wired through |
| `46` ambient temp | identical to IAT | echoes the intake sensor |
| `30` warm-ups | 255 | saturated at byte max |
| `13` O2 sensors present | `00` | not implemented |
| `51` fuel type | `00` | not implemented |

### Other modes

| Mode | Result |
|---|---|
| `03` / `07` | supported — `4300` / `4700`, no codes stored |
| `06` | **supported** — `46 00 C0000001` (catalyst/misfire monitors). Not yet explored |
| `09` | supported — VIN, calibration ID, ECU name |
| `02` freeze frame | `NO DATA` (nothing stored) |
| `08` control | `NO DATA` — not supported |
| `0A` permanent DTCs | supported — none stored |

---

## UDS service `0x22`

Service `0x22` **is supported** on both ECUs in the default session — no `0x27` security
access needed for these.

### Ranges swept, and what was found

| ECU | Ranges swept | Result |
|---|---|---|
| ECM | `F1xx` `F4xx` `01xx` `02xx` `03xx` `20xx` `D0xx` `F3xx` | identification only |
| ECM | full `0000`–`FFFF` pass (in progress) | **a dense `10xx` block** |
| TCM | `F1xx` `01xx` | identification only |

This section previously concluded **"no live-data DIDs found in any conventional range"**,
from 8 of 256 ranges on the ECM. The first full sweep contradicts it: by `233F` it had
found 190 identifiers, heavily concentrated from `1000` upward and answering with one or
two raw bytes each — not the ASCII strings the `F1xx` block returns. That is the shape of
manufacturer measurement blocks, and `10xx` was never among the ranges tried.

ISO 14229-1 puts `0100`–`A5FF` at the vehicle manufacturer's disposal, so nothing in the
standard names these. Identifying them means correlation, not lookup — see the DID watch
in the README.

Two cautions on that 190:

- **It is a floor.** The sweep ran over BLE at 6.0 identifiers/s, and this adapter drops
  responses (below). A DID that stayed silent may well answer next time.
- **Silence is not a refusal here.** 9023 tried produced exactly *one* negative response,
  so this ECU ignores unsupported identifiers rather than returning `0x7F`. "No reply" and
  "the adapter ate the reply" are therefore indistinguishable from the sweep alone.

### Identifiers that answer

| DID | ECU | Content |
|---|---|---|
| `F18A` | ECM | `BOSCH LIMITED` (system supplier) |
| `F189` | ECM | ECU software version |
| `F197` | ECM | system name |
| `F127` | ECM | `00` |
| `F190` | both | VIN |
| `F18C` | TCM | ECU serial number |
| `F192` | TCM | hardware number |
| `F194` | TCM | software number `285316301107` |
| `F187` | TCM | spare part number |
| `F180/81/82` | TCM | boot/app versions `06_N5_11`, `MA13`, `BB61` |
| `F183/84/85` | TCM | programming date `22 05 17` → **17 May 2022** |
| `1000`–`1008`… | ECM | manufacturer measurement block, 1–2 raw bytes each, meaning unknown |

Observed from the `10xx` block: `1000` = `91`, `1001` = `00 A3`, `1002` = `15 4F`,
`1003` = `14`, `1004` = `00 99`, `1005` = `00 D6`, `1006` = `61 8F`, `1007` = `00 20`.
Contiguous, and starting at a round address — a block, not scattered identifiers.

### The ELM327 clone drops UDS responses

Three sweeps of the same ECM range returned three different subsets:

| Run | ECM DIDs found |
|---|---|
| 1 | `F190` |
| 2 | `F127`, `F197` |
| 3 | `F127`, `F189`, `F18A` |

Union: 5. Best single run: 3. **The adapter loses responses**, so any single ELM327 sweep
undercounts. This is the strongest argument for the direct-CAN transport — not speed, but
*correctness*.

---

## Open questions

- What the `10xx` block holds. The DID watch logs a chosen handful beside the live PIDs;
  the work is fitting each column against a known value afterwards.
- Whether `10xx` is contiguous all the way up, and where it ends. The sweep was at `233F`.
- A repeat sweep over direct CAN, to find what the ELM327 dropped. ~30 min, versus 2h37m.
- Mode 06 monitor test results never read.
- Torque PIDs `61`/`62`/`63` scaling unverified — need data under load, not at idle.
- Bosch ME/MED17-family DID lists circulate publicly and may shortcut the brute-force.

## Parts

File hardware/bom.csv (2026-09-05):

# Obdurate Rev A bill of materials. variant is common | xiao or wroom.
# The buildable BOM for a variant is every 'common' row plus that variant's rows.
#
# status: spec = a real part number whose datasheet outline is settled
# class = the envelope is right | the SKU is still open
# estimate = the price needs a quote before it can be planned against
#
# mpn/mfr are what a turnkey assembler actually needs; they were added because an
# automated BOM matcher cannot price "2.2 uF 100 V X7R". Parts chosen for wide
# availability rather than optimality - substitute freely EXCEPT where the note
# says otherwise.
#
# dnp = do not populate. asm = n means it is not a component at all (bare copper
# the PCB itself | the case | the off-board connector) and must be kept out of any
# assembly BOM | or the matcher goes looking for a part called "test pad".
#
# value_tbd = the value comes off a datasheet and the one here is a placeholder
# good enough to quote against but NOT to build. Flagged in the note.
variant | designator | qty | value_or_mpn | manufacturer | package | footprint | status | usd_each | note | mpn | dnp | asm
common | W1-W5 | 5 | wire pad 2.0 mm |  | SMD pad | TestPoint:TestPoint_Pad_2.0x2.0mm | class | 0.00 | the five used J1 contacts land here; bare copper, nothing is placed on it |  | n | n
common | TP1-TP5 | 5 | test pad 2.0 mm |  | copper ENIG | TestPoint:TestPoint_Pad_2.0x2.0mm | class | 0.00 | 12V / CANH / CANL / 3V3 / GND pogo targets; bare copper |  | n | n
common | PCB | 1 | 40 x 40 mm 4 layer 1.6 mm |  | FR-4 TG150+ ENIG |  | class | 0.60 | colour is a product decision behind a clear case |  | n | n
common | CASE | 1 | SEP-A-OBD-M + SEP-A-OBD-B | Minitools | 50 x 48 x 24 |  | estimate | 4.20 | clear PC variant unconfirmed for -M; needs a quote |  | n | n
common | J1 | 1 | SEP-A-OBD-E2 | Minitools | 43 x 21 module |  | spec | 2.60 | OBD-II male J1962, 16 pin, 5 used. Off-board: wires to W1..W5 | SEP-A-OBD-E2 | n | n
common | U1 | 1 | SN65HVD230DR | Texas Instruments | SOIC-8 | Package_SO:SOIC-8_3.9x4.9mm_P1.27mm | spec | 0.90 | 3.3 V CAN transceiver; Rs to GND for high-speed; no split termination | SN65HVD230DR | n | y
common | U2 | 1 | LM5164QDDARQ1 | Texas Instruments | SO PowerPAD-8 | Package_SO:SOIC-8-1EP_3.9x4.9mm_P1.27mm_EP2.29x3mm | spec | 2.60 | NO SUBSTITUTION. It is here for 100 V tolerance and 10 uA idle; a swap to a 36 V part fails a load dump silently. AVAILABLE in India - LionCircuits quoted it at INR 539 at qty 1, so the earlier note about consigning it was wrong | LM5164QDDARQ1 | n | y
common | L1 | 1 | 33 uH shielded | Bourns | 6.0 x 6.0 x 4.5 | Inductor_SMD:L_Bourns_SRN6045TA | class | 0.55 | value_tbd - confirm against the LM5164 application circuit. 4.5 mm tall, which sets minimum internal clearance | SRN6045TA-330M | n | y
common | CH1 | 1 | CAN common-mode choke | TDK | 4.5 x 3.2 (ACM4532) | Inductor_SMD:L_CommonModeChoke_Coilank_ACM4532 | class | 0.15 | 4-terminal automotive CAN choke | ACM4532-231-2P-T | n | y
common | D1 | 1 | SMAJ33A | Littelfuse | DO-214AC (SMA) | Diode_SMD:D_SMA | class | 0.12 | TVS clamp to GND | SMAJ33A | n | y
common | D2 | 1 | NUP2105LT1G | onsemi | SOT-23 | Package_TO_SOT_SMD:SOT-23 | class | 0.11 | CAN ESD array | NUP2105LT1G | n | y
common | D4 | 1 | 10 V zener | Diodes Inc | SOD-323 | Diode_SMD:D_SOD-323 | class | 0.04 | 10 V not 15 V: it clamps Q1 gate-source, and AO3401A is rated +-12 V Vgs. A 15 V zener would exceed the gate rating | BZT52C10-7-F | n | y
common | Q1 | 1 | AO3401A | Alpha & Omega | SOT-23 | Package_TO_SOT_SMD:SOT-23 | class | 0.08 | reverse-polarity P-FET. -30 V Vds is ample: it blocks a reversed battery, and U2 handles the load dump. Widely stocked in India | AO3401A | n | y
common | F1 | 1 | polyfuse 0.5 A hold | Littelfuse | 1206 | Fuse:Fuse_1206_3216Metric | class | 0.10 | resettable | 1206L050YR | n | y
common | C1 | 1 | 1 uF 100 V X7R | Murata | 1210 | Capacitor_SMD:C_1210_3225Metric | class | 0.14 | VIN bulk. 1 uF not 2.2 uF: 2.2 uF at 100 V in 1210 is a specialty size that BOTH vendors failed to identify, while 1 uF 100 V is commodity. Two of these give 2 uF, and the 100 V rating is what matters here - it is for load-dump survival, not capacitance precision. ANY equivalent 1 uF 100 V X7R 1210 is fine | GRM32DR72A105KA01L | n | y
common | C2 | 1 | 1 uF 100 V X7R | Murata | 1210 | Capacitor_SMD:C_1210_3225Metric | class | 0.14 | VIN bulk, pairs with C1. Substitution welcome - this is not a NO SUBSTITUTION line | GRM32DR72A105KA01L | n | y
common | C3 | 1 | 22 uF 25 V X7R | Murata | 1210 | Capacitor_SMD:C_1210_3225Metric | class | 0.09 | buck output. 25 V part suits the 5 V xiao rail and is over-rated for wroom's 3.3 V, which is fine | GRM32ER71E226KE15L | n | y
common | C4 | 1 | 22 uF 25 V X7R | Murata | 1210 | Capacitor_SMD:C_1210_3225Metric | class | 0.09 | buck output | GRM32ER71E226KE15L | n | y
common | C8 | 1 | 0.1 uF 100 V X7R | Murata | 0603 | Capacitor_SMD:C_0603_1608Metric | class | 0.02 | VIN high-frequency bypass at U2's pin | GRM188R72A104KA35D | n | y
common | C9 | 1 | 0.1 uF 50 V X7R | Murata | 0603 | Capacitor_SMD:C_0603_1608Metric | class | 0.01 | BST to SW bootstrap. Without it the high-side FET never fully turns on | GRM188R71H104KA93D | n | y
common | R2 | 1 | 100 k 1% | Yageo | 0603 | Resistor_SMD:R_0603_1608Metric | class | 0.01 | Q1 gate to GND | RC0603FR-07100KL | n | y
common | R7 | 1 | 0 ohm | Yageo | 0603 | Resistor_SMD:R_0603_1608Metric | class | 0.01 | U1 Rs to GND for high-speed mode | RC0603JR-070RL | n | y
common | R8 | 1 | 100 k 1% | Yageo | 0603 | Resistor_SMD:R_0603_1608Metric | class | 0.01 | value_tbd - EN/UVLO upper. 100k/22k trips near 7 V against a 1.26 V reference; confirm the reference from the datasheet | RC0603FR-07100KL | n | y
common | R9 | 1 | 22 k 1% | Yageo | 0603 | Resistor_SMD:R_0603_1608Metric | class | 0.01 | value_tbd - EN/UVLO lower, pairs with R8 | RC0603FR-0722KL | n | y
common | R10 | 1 | 52.3 k 1% | Yageo | 0603 | Resistor_SMD:R_0603_1608Metric | class | 0.01 | value_tbd - FB upper. 52.3k/10k gives 5 V against a 0.8 V reference, which is the XIAO variant. The wroom variant needs a different ratio for 3.3 V | RC0603FR-0752K3L | n | y
common | R11 | 1 | 10 k 1% | Yageo | 0603 | Resistor_SMD:R_0603_1608Metric | class | 0.01 | value_tbd - FB lower, pairs with R10 | RC0603FR-0710KL | n | y
common | R12 | 1 | 100 k 1% | Yageo | 0603 | Resistor_SMD:R_0603_1608Metric | class | 0.01 | value_tbd - RON sets the on-time and so the switching frequency. Straight off the datasheet | RC0603FR-07100KL | n | y
xiao | U3 | 1 | XIAO ESP32S3 | Seeed Studio | 21 x 17.5 module | RF_Module:MCU_Seeed_ESP32C3 | spec | 7.00 | 8 MB PSRAM + 8 MB flash, U.FL antenna included. Footprint is the shared XIAO land pattern. Stocked by Indian distributors - consider consigning | 102010551 | n | y
xiao | D5 | 1 | 1N5819HW-7-F | Diodes Inc | SOD-123 | Diode_SMD:D_SOD-123 | class | 0.08 | REQUIRED, 1 A 40 V Schottky. The XIAO's 5V pad is not diode-isolated from VBUS; without this, USB back-powers the host | 1N5819HW-7-F | n | y
xiao | R13 | 1 | 0 ohm | Yageo | 0603 | Resistor_SMD:R_0603_1608Metric | class | 0.01 | links the module's 3V3 out to U1. Fit this OR U5, never both | RC0603JR-070RL | n | y
xiao | U5 | 1 | AP2112K-3.3TRG1 | Diodes Inc | SOT-23-5 | Package_TO_SOT_SMD:SOT-23-5 | class | 0.00 | DO NOT POPULATE on Rev A - footprint only. Fit instead of R13 if the module regulator lacks headroom for U1's ~70 mA | AP2112K-3.3TRG1 | y | y
wroom | U3 | 1 | ESP32-S3-WROOM-1-N8R8 | Espressif | 18.0 x 25.5 x 3.1 | RF_Module:ESP32-S3-WROOM-1 | spec | 3.20 | PCB antenna; needs a host keepout; place at the board edge | ESP32-S3-WROOM-1-N8R8 | n | y
wroom | J2 | 1 | USB-C receptacle 16P | GCT | SMD | Connector_USB:USB_C_Receptacle_GCT_USB4085 | class | 0.30 | 0.5 mm pitch - the finest on this variant, and what sets its fab class | USB4085-GF-A | n | y
wroom | U4 | 1 | AP2112K-3.3TRG1 | Diodes Inc | SOT-23-5 | Package_TO_SOT_SMD:SOT-23-5 | class | 0.15 | USB 5 V rail; the buck cannot run from 5 V | AP2112K-3.3TRG1 | n | y
wroom | D3 | 1 | BAT54 | Diodes Inc | SOD-323 | Diode_SMD:D_SOD-323 | class | 0.05 | ORs the USB rail into 3V3. Leaves the USB-only rail near 3.05 V - see README | BAT54W-7-F | n | y
wroom | C5 | 1 | 10 uF 16 V X7R | Murata | 0603 | Capacitor_SMD:C_0603_1608Metric | class | 0.02 | at U3's own 3V3 pin per Espressif's guidelines | GRM188R61C106MA73D | n | y
wroom | C6 | 1 | 0.1 uF 50 V X7R | Murata | 0603 | Capacitor_SMD:C_0603_1608Metric | class | 0.01 | at U3's own 3V3 pin | GRM188R71H104KA93D | n | y
wroom | C7 | 1 | 1 uF 16 V X7R | Murata | 0603 | Capacitor_SMD:C_0603_1608Metric | class | 0.01 | EN reset RC | GRM188R71C105KA12D | n | y
wroom | R1 | 1 | 1 k 1% | Yageo | 0603 | Resistor_SMD:R_0603_1608Metric | class | 0.01 | LED1 series. GPIO21 is active low so the pin sinks | RC0603FR-071KL | n | y
wroom | R3 | 1 | 10 k 1% | Yageo | 0603 | Resistor_SMD:R_0603_1608Metric | class | 0.01 | IO0 BOOT pull-up | RC0603FR-0710KL | n | y
wroom | R4 | 1 | 10 k 1% | Yageo | 0603 | Resistor_SMD:R_0603_1608Metric | class | 0.01 | EN pull-up | RC0603FR-0710KL | n | y
wroom | R5 | 1 | 5.1 k 1% | Yageo | 0603 | Resistor_SMD:R_0603_1608Metric | class | 0.01 | USB-C CC1 | RC0603FR-075K1L | n | y
wroom | R6 | 1 | 5.1 k 1% | Yageo | 0603 | Resistor_SMD:R_0603_1608Metric | class | 0.01 | USB-C CC2 | RC0603FR-075K1L | n | y
wroom | LED1 | 1 | LED green 0603 | Wurth | 0603 | LED_SMD:LED_0603_1608Metric | class | 0.04 | status. The xiao variant needs none - the module's own LED IS GPIO21 | 150060GS75000 | n | y
wroom | TP6 | 1 | test pad 2.0 mm |  | copper ENIG | TestPoint:TestPoint_Pad_2.0x2.0mm | class | 0.00 | BOOT. Bare copper, nothing is placed on it |  | n | n

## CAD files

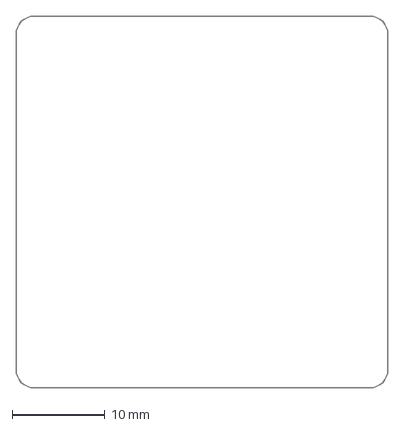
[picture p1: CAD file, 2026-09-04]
hardware/outline.dxf
40.0 x 40.0 mm

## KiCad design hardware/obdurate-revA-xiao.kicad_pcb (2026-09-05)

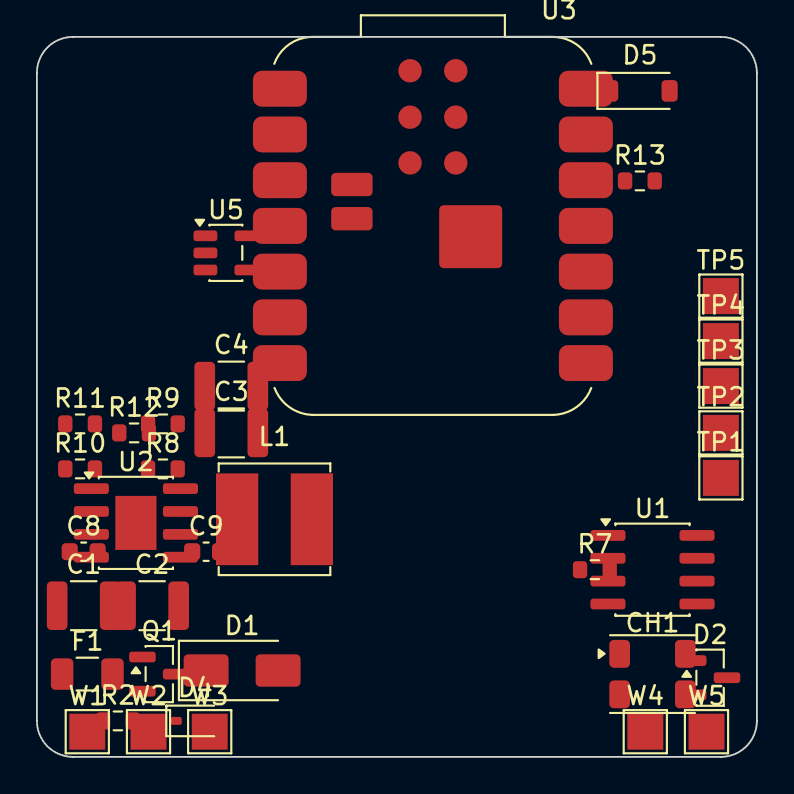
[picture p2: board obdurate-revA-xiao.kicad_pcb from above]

Board: 4 copper layers, 40.0 x 40.0 mm, 36 parts (0 on the bottom side), 21 nets, no tracks yet.

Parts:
C1, C2: 2.2 uF 100 V; C_1210_3225Metric
C3, C4: 22 uF; C_1210_3225Metric
C8: 0.1 uF 100 V; C_0603_1608Metric
C9: 0.1 uF bootstrap; C_0603_1608Metric
CH1: CAN common-mode choke; L_CommonModeChoke_Coilank_ACM4532
D1: SMAJ33A; D_SMA
D2: NUP2105L; SOT-23
D4: 15 V zener; D_SOD-323
D5: Schottky 1 A; D_SOD-123
F1: polyfuse 500 mA; Fuse_1206_3216Metric
L1: 33 uH inductor; L_Bourns_SRN6045TA
Q1: P-ch MOSFET; SOT-23
R2: 100 k; R_0603_1608Metric
R7: 0 ohm; R_0603_1608Metric
R8: EN/UVLO upper; R_0603_1608Metric
R9: EN/UVLO lower; R_0603_1608Metric
R10: FB upper; R_0603_1608Metric
R11: FB lower; R_0603_1608Metric
R12: RON; R_0603_1608Metric
R13: 0 ohm link; R_0603_1608Metric
TP1: test pad 12V; TestPoint_Pad_2.0x2.0mm
TP2: test pad CANH; TestPoint_Pad_2.0x2.0mm
TP3: test pad CANL; TestPoint_Pad_2.0x2.0mm
TP4: test pad 3V3; TestPoint_Pad_2.0x2.0mm
TP5: test pad GND; TestPoint_Pad_2.0x2.0mm
U1: SN65HVD230DR; SOIC-8_3.9x4.9mm_P1.27mm
U2: LM5164-Q1; SOIC-8-1EP_3.9x4.9mm_P1.27mm_EP2.29x3mm
U3: XIAO ESP32S3; MCU_Seeed_ESP32C3
U5: AP2112K-3.3 (DNP); SOT-23-5
W1: wire pad V_BATT; TestPoint_Pad_2.0x2.0mm
W2, W3: wire pad GND; TestPoint_Pad_2.0x2.0mm
W4: wire pad CAN_H; TestPoint_Pad_2.0x2.0mm
W5: wire pad CAN_L; TestPoint_Pad_2.0x2.0mm

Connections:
3V3: R13.2, TP4.1, U1.3, U5.5
BST: C9.1, U2.7
CAN_H: CH1.1, D2.1, TP2.1, W4.1
CAN_H_F: CH1.2, U1.7
CAN_L: CH1.3, D2.3, TP3.1, W5.1
CAN_L_F: CH1.4, U1.6
CRX: U1.4, U3.3
CTX: U1.1, U3.2
FB: R10.2, R11.1, U2.5
GND: C1.2, C2.2, C3.2, C4.2, C8.2, D1.2, D2.2, R2.2, R7.2, R9.2, R11.2, R12.2, TP5.1, U1.2, U2.1, U2.9, U3.13, U5.2, W2.1, W3.1
RON: R12.1, U2.4
RS: R7.1, U1.8
SW: C9.2, L1.1, U2.8
UVLO: R8.2, R9.1, U2.3
V5: D5.1, U3.14, U5.1
VF: D4.1, F1.2, Q1.2
VGATE: D4.2, Q1.1, R2.1
VOUT: C3.1, C4.1, D5.2, L1.2, R10.1
V_BATT: F1.1, TP1.1, W1.1
V_IN: C1.1, C2.1, C8.1, D1.1, Q1.3, R8.1, U2.2
XIAO_3V3: R13.1, U3.12

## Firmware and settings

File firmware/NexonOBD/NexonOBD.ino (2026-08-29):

// NexonOBD - XIAO ESP32S3 + SN65HVD230 CAN transceiver, plugged into the OBD-II port.
//
// Two modes, one binary:
//   1. Live dashboard  - hosts a Wi-Fi AP and serves gauges at http://192.168.4.1/
//   2. UDS DID scanner - brute-forces service 0x22 across the identifier space
//
// Talks raw ISO 15765-4 (CAN 11-bit / 500 kbit) with a real ISO-TP layer, so it
// replaces the ELM327 rather than depending on it. Bluetooth is not used at all:
// the XIAO ESP32S3 is BLE-only and cannot speak the Classic SPP an ELM327 needs.
//
// SAFETY: this firmware only ever transmits diagnostic requests - mode 01 (live
// data), mode 03 (stored codes), mode 06 (on-board monitor results) and UDS service
// 0x22 (ReadDataByIdentifier), all of them reads - plus ISO-TP flow-control frames.
// It never sends arbitrary frames, never writes (0x2E), never runs routines (0x31),
// never resets an ECU (0x11), never changes diagnostic session (0x10) and never
// clears the car's own record (0x14).
//
// That is checked, not asserted: test_dashboard.mjs finds every request buffer from
// its call sites, reads its service byte out of this file, and fails the build on
// anything outside the list of reads. This comment claimed mode 09 for a long time
// while no 0x09 request existed anywhere in the sketch; writing the check is what
// found it.

#include <Arduino.h>
#include <WiFi.h>
#include <WebServer.h>
#include <vector>
#include "driver/twai.h"
#include "esp_system.h"
#include "obd_types.h"
#include "bus_yield.h"
#include "elm_ble.h"
#include "version.h"
#include "history.h"
#include "clock.h"
#include "didwatch.h"
#include "ui_paths.h"
#include "ui_fs.h"
#include "triplog.h"
#include <Update.h>
#include "boot_html.h"
#include "ui_html.h"
#include "ota_html.h"

// Two ways to reach the car, picked at runtime:
//   TR_CAN - SN65HVD230 transceiver on pins D1/D2, straight onto the bus. Fast.
//   TR_BLE - BLE GATT to the dual-mode ELM327 already plugged into the OBD port.
//            Slower, but needs no extra hardware at all.
enum Transport { TR_NONE, TR_CAN, TR_BLE };
static Transport activeTransport = TR_NONE;

// ---------------------------------------------------------------- config

static const gpio_num_t PIN_CAN_TX = GPIO_NUM_2;   // XIAO pad D1
static const gpio_num_t PIN_CAN_RX = GPIO_NUM_3;   // XIAO pad D2

static const char *AP_SSID = "NexonOBD";
static const char *AP_PASS = "nexon1234";          // >= 8 chars, change if you like

static const uint32_t ID_ECM_REQ = 0x7E0;          // engine ECU request
static const uint32_t ID_ECM_RSP = 0x7E8;          // engine ECU response
static const uint32_t ID_TCM_REQ = 0x7E1;          // transmission
static const uint32_t ID_TCM_RSP = 0x7E9;

// Deep-sleep after this long with no ECU response, so the car battery survives
// the thing being left plugged in. OBD pin 16 is permanently live.
static const uint32_t IDLE_SLEEP_MS = 10UL * 60UL * 1000UL;
static const uint64_t SLEEP_WAKE_US = 30ULL * 1000000ULL;   // re-check every 30 s

// A second floor, under the idle timer rather than beside it.
//
// The idle timer answers "the car is off", which is the ordinary case. It does not
// answer "the battery is going flat", and those come apart precisely where it
// matters: an ECU that keeps answering with the engine not running - ignition on at
// the roadside, a long diagnostic session parked, a module that stays awake - resets
// lastEcuOkMs on every reply, so the ten-minute guard never arms and the board draws
// from a battery nothing is charging for as long as that lasts.
//
// A lead-acid battery at rest sits near 12.6 V. 11.8 V is roughly a quarter charged
// and about where a cold start stops being a certainty. Past that, nothing this board
// does is worth the car not starting.
static const float    BATT_SLEEP_V       = 11.8f;
// Cranking pulls the rail to nine volts and below for a second or so, which is the
// one moment the reading is low and sleeping would be exactly wrong. Thirty seconds
// continuously below the floor is well past any crank, and past the sag from an
// electric fan or a heated screen starting up.
static const uint32_t BATT_SLEEP_HOLD_MS = 30000;
// The engine turning is proof something is charging, whatever the rail reads.
static const float    BATT_ENGINE_RPM    = 300.0f;

// Boot forensics.
//
// A recorder that runs unattended has to be able to answer "what happened while I
// was not looking". From the page, a board that has quietly panicked and restarted
// forty times looks exactly like one that has been up all week - same version, same
// readings, a trip log full of short files nobody can explain. A brownout in
// particular is a car-electrical event worth seeing, and it is invisible today.
//
// The counter lives in RTC memory, which does not survive a power cut - and that is
// correct rather than a limitation, because it counts deep-sleep wakes and those
// are precisely the restarts RTC memory does survive. A cold boot resets it, which
// esp_reset_reason() can say for certain, so no magic word is needed here.
RTC_DATA_ATTR static uint32_t g_bootWakes;

static const char *resetReasonName() {
  switch (esp_reset_reason()) {
    case ESP_RST_POWERON:   return "power";
    case ESP_RST_DEEPSLEEP: return "wake";
    case ESP_RST_SW:        return "software";
    case ESP_RST_PANIC:     return "panic";
    case ESP_RST_INT_WDT:   return "int-wdt";
    case ESP_RST_TASK_WDT:  return "task-wdt";
    case ESP_RST_WDT:       return "wdt";
    case ESP_RST_BROWNOUT:  return "brownout";
    case ESP_RST_EXT:       return "external";
    default:                return "unknown";
  }
}

// The XIAO ESP32S3 has no power LED - the only visible indicator is the user LED
// on GPIO21, and it is active LOW. Without this the board looks dead even when
// it is working, which is no good when it is wedged under the dashboard.
#ifndef LED_BUILTIN
#define LED_BUILTIN 21
#endif
static const uint8_t LED_PIN = LED_BUILTIN;

// Heartbeat encodes state at a glance:
//   slow 1 Hz  - alive, Wi-Fi up, but no ECU response (ignition off / not wired)
//   fast 5 Hz  - talking to the ECU
//   double-blink - DID scan in progress
static void heartbeat(bool ecuOk, bool scanning) {
  static uint32_t last = 0;
  static uint8_t phase = 0;
  uint32_t period = scanning ? 120 : (ecuOk ? 100 : 500);
  if (millis() - last < period) return;
  last = millis();
  phase++;
  bool on;
  if (scanning) on = (phase % 6) < 2;            // blip-blip-pause
  else          on = (phase & 1);
  digitalWrite(LED_PIN, on ? LOW : HIGH);        // active LOW
}

WebServer server(80);

// ---------------------------------------------------------------- HTTP fairness

// Set while inside a request handler. WebServer keeps a single current client, so
// re-entering handleClient() from within a handler would corrupt it. handleDtc is
// the one handler that waits on the bus, and it therefore does not yield - which is
// why its timeouts are kept short.
static bool g_inHandler = false;

// Set for the duration of one ISO-TP exchange. A handler reached from webYield() is
// running underneath a half-finished reassembly, so it must not start a second
// exchange on top of it.
static bool g_busBusy = false;

static void serveHttp() {
  g_inHandler = true;
  server.handleClient();
  g_inHandler = false;
}

// Called from the transports' wait loops - see bus_yield.h for why the time is
// given back to the response deadline.
uint32_t webYield() {
  if (g_inHandler) return 0;
  uint32_t t0 = millis();
  serveHttp();
  return millis() - t0;
}

// ---------------------------------------------------------------- CAN / ISO-TP

static bool canUp = false;

static bool canBegin() {
  twai_general_config_t g = TWAI_GENERAL_CONFIG_DEFAULT(PIN_CAN_TX, PIN_CAN_RX, TWAI_MODE_NORMAL);
  g.rx_queue_len = 48;
  g.tx_queue_len = 16;
  twai_timing_config_t t = TWAI_TIMING_CONFIG_500KBITS();
  twai_filter_config_t f = TWAI_FILTER_CONFIG_ACCEPT_ALL();

  if (twai_driver_install(&g, &t, &f) != ESP_OK) return false;
  if (twai_start() != ESP_OK) return false;
  return true;
}

// Drain until the bus has actually gone quiet, not just until the queue happens to
// be empty this instant.
//
// A request that timed out mid-reassembly leaves its consecutive frames still in
// flight. A single non-blocking drain returns before they land, so they arrive
// inside the *next* request's read loop, where a stale CF with the wrong sequence
// number kills a perfectly good exchange - one failed poll turning into a run of
// them, which is what made the status text flicker between live and "no response".
static void canFlush() {
  twai_message_t m;
  uint32_t quietSince = millis();
  while (millis() - quietSince < 4) {
    if (twai_receive(&m, pdMS_TO_TICKS(1)) == ESP_OK) quietSince = millis();
  }
}

static bool canSend(uint32_t id, const uint8_t *d, uint8_t len) {
  twai_message_t m = {};
  m.identifier = id;
  m.data_length_code = 8;
  for (int i = 0; i < 8; i++) m.data[i] = (i < len) ? d[i] : 0x55;   // 0x55 pad
  return twai_transmit(&m, pdMS_TO_TICKS(30)) == ESP_OK;
}

// One request, one reassembled response. Handles single frame, first frame +
// flow control + consecutive frames, and the 0x78 "responsePending" negative reply.
// Returns payload length, or -1 on timeout, -2 on a real negative response, or
// -3 when reassembly started but never completed.
//
// -3 has to be distinct from a short payload. Returning however many bytes did
// arrive makes a truncated reply indistinguishable from a complete one, so the
// caller parses half a batch and treats the PIDs that never arrived as absent -
// which is what blanks the dashboard mid-drive.
static int canIsoTp(uint32_t reqId, uint32_t rspId,
                    const uint8_t *payload, uint8_t plen,
                    uint8_t *out, size_t outCap, uint32_t timeoutMs,
                    int *partial = nullptr) {
  if (partial) *partial = 0;
  // A single frame is eight bytes: one of PCI and seven of payload. Nothing here
  // sends a multi-frame request, so anything longer is a caller error - and it used
  // to be a silent one, because the memcpy below is into a stack buffer with no
  // bound. Every current caller passes a constant, and the largest of them - the
  // mode 01 batch at PID_B*, six PIDs plus the mode byte - is exactly 7. That is at
  // the limit with nothing spare, which is precisely the shape of a bug that waits:
  // a seventh PID in a batch, or packing two DIDs into one 0x22 request, smashes the
  // frame on the stack and nothing says so.
  if (plen > 7) return -1;
  uint8_t frame[8] = {0};
  frame[0] = plen;                                  // single-frame PCI
  memcpy(&frame[1], payload, plen);
  canFlush();
  if (!canSend(reqId, frame, plen + 1)) return -1;

  size_t got = 0, total = 0;
  bool multi = false;
  uint8_t nextSeq = 1;
  uint32_t deadline = millis() + timeoutMs;
  uint32_t extended = 0;

  while ((int32_t)(deadline - millis()) > 0) {
    twai_message_t m;
    // Nothing on the bus this instant: serve any waiting HTTP request rather than
    // spinning, and give the deadline back the time that took.
    if (twai_receive(&m, pdMS_TO_TICKS(5)) != ESP_OK) { busWaitYield(deadline, extended); continue; }
    if (m.identifier != rspId) continue;

    uint8_t pci = m.data[0] >> 4;

    if (pci == 0x0) {                               // single frame
      uint8_t len = m.data[0] & 0x0F;
      if (len > 7) return -1;
      // negative response?
      if (len >= 3 && m.data[1] == 0x7F) {
        if (m.data[3] == 0x78) { deadline = millis() + timeoutMs + 200; continue; }  // pending
        return -2;
      }
      if (len > outCap) return -3;                  // will not fit - do not half-copy it
      memcpy(out, &m.data[1], len);
      return (int)len;
    }
    else if (pci == 0x1) {                          // first frame
      total = (((size_t)(m.data[0] & 0x0F)) << 8) | m.data[1];
      if (total > outCap) return -3;                // would truncate during reassembly
      multi = true;
      got = min((size_t)6, total);
      memcpy(out, &m.data[2], got);
      uint8_t fc[3] = {0x30, 0x00, 0x00};           // clear to send, no block, no delay
      canSend(reqId, fc, 3);
      nextSeq = 1;
      deadline = millis() + timeoutMs + 300;
    }
    else if (pci == 0x2 && multi) {                 // consecutive frame
      if ((m.data[0] & 0x0F) != nextSeq) return -3; // dropped or reordered frame
      nextSeq = (nextSeq + 1) & 0x0F;
      size_t n = min((size_t)7, total - got);
      memcpy(out + got, &m.data[1], n);
      got += n;
      if (got >= total) return (int)got;
    }
  }
  if (multi && partial) *partial = (int)got;        // salvageable if the caller can verify it
  return multi ? -3 : -1;                           // a partial reassembly is not a result
}

// ---------------------------------------------------------------- BLE transport

static uint32_t bleCurHeader = 0;

static int hexNib(char c) {
  if (c >= '0' && c <= '9') return c - '0';
  if (c >= 'A' && c <= 'F') return c - 'A' + 10;
  if (c >= 'a' && c <= 'f') return c - 'a' + 10;
  return -1;
}

// Same request/response contract as canIsoTp, but spoken as ELM327 text over BLE.
// Headers are left ON and the reply lines are demultiplexed by responder ID here,
// because this clone's ATCRA receive filter does not actually filter.
static int bleIsoTp(uint32_t reqId, uint32_t rspId,
                    const uint8_t *payload, uint8_t plen,
                    uint8_t *out, size_t outCap, uint32_t timeoutMs,
                    int *partial = nullptr) {
  if (partial) *partial = 0;
  if (!elmConnected) return -1;

  if (bleCurHeader != reqId) {
    char h[16];
    snprintf(h, sizeof(h), "ATSH %03X", (unsigned)reqId);
    elmCommand(h, 800);
    bleCurHeader = reqId;
  }

  char cmd[40];
  int n = 0;
  for (uint8_t i = 0; i < plen && n < (int)sizeof(cmd) - 3; i++)
    n += snprintf(cmd + n, sizeof(cmd) - n, "%02X", payload[i]);

  String resp = elmCommand(String(cmd), timeoutMs);
  if (resp.length() == 0) return -1;
  if (resp.indexOf("UNABLE") >= 0 || resp.indexOf("NO DATA") >= 0) return -1;

  char want[4];
  snprintf(want, sizeof(want), "%03X", (unsigned)rspId);

  size_t got = 0, total = 0;
  bool multi = false, negative = false, broken = false;
  uint8_t nextSeq = 1;

  int start = 0;
  while (start < (int)resp.length()) {
    int nl = resp.indexOf('\r', start);
    int nl2 = resp.indexOf('\n', start);
    if (nl < 0 || (nl2 >= 0 && nl2 < nl)) nl = nl2;
    String line = (nl < 0) ? resp.substring(start) : resp.substring(start, nl);
    start = (nl < 0) ? resp.length() : nl + 1;

    line.replace(" ", "");
    line.trim();
    if (line.length() < 5) continue;
    if (!line.startsWith(want)) continue;

    String body = line.substring(3);
    int hi = hexNib(body[0]), lo = hexNib(body[1]);
    if (hi < 0 || lo < 0) continue;
    uint8_t pci = (uint8_t)((hi << 4) | lo);

    // decode the remaining hex characters of this line into bytes
    uint8_t tmp[32];
    size_t tn = 0;
    for (size_t i = 2; i + 1 < body.length() && tn < sizeof(tmp); i += 2) {
      int a = hexNib(body[i]), b = hexNib(body[i + 1]);
      if (a < 0 || b < 0) break;
      tmp[tn++] = (uint8_t)((a << 4) | b);
    }

    if ((pci & 0xF0) == 0x00) {                 // single frame
      size_t len = pci & 0x0F;
      if (len >= 3 && tn >= 3 && tmp[0] == 0x7F) { negative = true; continue; }
      if (len > tn || len > outCap) { broken = true; continue; }   // line cut short
      memcpy(out, tmp, len);
      return (int)len;
    } else if ((pci & 0xF0) == 0x10) {          // first frame: 12-bit length
      if (tn < 1) continue;
      total = (((size_t)(pci & 0x0F)) << 8) | tmp[0];
      if (total > outCap) { broken = true; continue; }
      multi = true;
      got = min(tn - 1, total);
      memcpy(out, tmp + 1, got);
      nextSeq = 1;
    } else if ((pci & 0xF0) == 0x20 && multi) { // consecutive frame
      // Sequence has to be checked here, not just the byte count: this clone drops
      // whole responses (see FINDINGS), and a missing middle frame otherwise slots
      // the following frame's bytes into the gap and corrupts everything after it.
      if ((pci & 0x0F) != nextSeq) { broken = true; continue; }
      nextSeq = (nextSeq + 1) & 0x0F;
      size_t cnt = min(tn, total - got);
      memcpy(out + got, tmp, cnt);
      got += cnt;
      if (got >= total) return (int)got;
    }
  }

  if (negative) return -2;
  if (multi && partial) *partial = (int)got;    // salvageable if the caller can verify it
  return (multi || broken) ? -3 : -1;           // started but never completed
}

// Dispatcher - everything above the transport layer calls this.
static int obdIsoTp(uint32_t reqId, uint32_t rspId,
                    const uint8_t *payload, uint8_t plen,
                    uint8_t *out, size_t outCap, uint32_t timeoutMs,
                    int *partial = nullptr) {
  // The same seven-byte single-frame limit canIsoTp enforces, stated once at the
  // door so both transports refuse an over-long request identically rather than one
  // truncating it into a valid-looking shorter request.
  if (plen == 0 || plen > 7) return -1;
  // One exchange at a time. The wait loops below serve HTTP, so a handler can run
  // underneath a half-finished reassembly; a second request issued from there would
  // interleave its frames with ours and corrupt both.
  g_busBusy = true;
  int r = (activeTransport == TR_BLE)
        ? bleIsoTp(reqId, rspId, payload, plen, out, outCap, timeoutMs, partial)
        : canIsoTp(reqId, rspId, payload, plen, out, outCap, timeoutMs, partial);
  g_busBusy = false;
  return r;
}

// ---------------------------------------------------------------- mode 01

// Data-field byte count per SAE J1979 PID.
static uint8_t pidLen(uint8_t pid) {
  switch (pid) {
    case 0x0C: case 0x1F: case 0x3C: case 0x42: case 0x5E:
    case 0x43: case 0x63: return 2;
    case 0x34: return 4;
    default:   return 1;
  }
}
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
void loop() {
  for (int i = 0; i < HTTP_DRAIN; i++) serveHttp();
  samplerStep();          // the bus waits inside here serve HTTP too - bus_yield.h
  watchStep();            // one watched identifier per period, paused during a scan
  monStep();              // only does anything while the monitors page is open
  heartbeat(millis() - lastEcuOkMs < 3000, scan.running);

  if (scan.running) {
    if (!scan.stalled) lastEcuOkMs = millis();   // a stalled scan is not activity
    scanStep(250);                // then hand the web server a turn
    static uint32_t scanCkpt = 0;
    if (millis() - scanCkpt > 5000) { scanCkpt = millis(); scanSaveState(); }
  }

  // Periodic status line. setup() output is lost because the USB CDC
  // re-enumerates at boot, so a running board must announce itself repeatedly
  // or there is no way to tell it apart from one stuck in the ROM loader.
  static uint32_t lastLog = 0;
  if (millis() - lastLog > 3000) {
    lastLog = millis();
    Serial.printf("[alive] up=%lus tr=%s can=%s ble=%s ap=%s clients=%u ecu=%s scan=%s "
                  "batch=%lums cycle=%lums stale=%lums\n",
                  millis() / 1000UL,
                  transportName(),
                  canUp ? "ok" : "FAIL",
                  elmConnected ? "up" : "down",
                  WiFi.softAPIP().toString().c_str(),
                  WiFi.softAPgetStationNum(),
                  (millis() - lastEcuOkMs < 3000) ? "ok" : "silent",
                  scan.running ? "running" : "idle",
                  (unsigned long)sampBatchMs,
                  (unsigned long)sampCycleMs,
                  (unsigned long)sampleStaleMs(sampCycleMs));
  }

  // Re-pick the transport while nothing is answering: covers the ELM327 dropping
  // its BLE link, a stale link held over from before the board lost power, or a
  // transceiver being wired in later.
  static uint32_t lastPick = 0;
  if (!scan.running && millis() - lastEcuOkMs > 3000 && millis() - lastPick > pickWaitMs) {
    lastPick = millis();
    Serial.printf("[obd] no data for %lums - re-picking transport (next in %lums)\n",
                  (unsigned long)(millis() - lastEcuOkMs), (unsigned long)pickWaitMs);
    chooseTransport();
    pickWaitMs = pickBackoff(pickWaitMs);
  }

  // Battery guard: nothing from the car for a while means the ignition is off.
  // Only arms once the ECU has actually answered at least once, otherwise a
  // bench board with no transceiver wired would sleep mid-test and look dead.
  if (everSawEcu && millis() - lastEcuOkMs > IDLE_SLEEP_MS) powerDown("idle");

  // The battery floor, under the idle timer rather than beside it. Only ever on a
  // fresh sample: g_live keeps its last values once the ECU stops answering, and a
  // voltage from ten minutes ago must not put the board to sleep now - that case is
  // the idle timer's, and it is already running.
  bool freshSample = g_seq && (millis() - g_liveMs < 4000);
  g_battLow = battLowStep(g_battLow,
                          freshSample ? g_live.volt : NAN,
                          freshSample ? g_live.rpm : NAN,
                          millis());
  if (g_battLow && millis() - g_battLow >= BATT_SLEEP_HOLD_MS) {
    char why[48];
    snprintf(why, sizeof(why), "battery %.2f V, engine stopped", (double)g_live.volt);
    powerDown(why);
  }
}

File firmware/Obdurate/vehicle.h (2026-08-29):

#pragma once
#include <Arduino.h>

// What car is this, and what can it actually answer?
//
// Everything else in this firmware is written against one vehicle. The PID batches
// in the sketch are the set a Nexon replies to, the register holds 214 verdicts
// about a Nexon's ECU, and the dashboard draws tiles for readings that car
// publishes. Plug the board into anything else and none of that announces itself:
// the tiles that cannot be filled read blank, which is indistinguishable from a
// car that is simply not answering yet.
//
// So: ask. Mode 01 PID 00 and its continuations are a bitmap of every live PID the
// ECU supports, and mode 09 carries the VIN, the calibration id and its checksum.
// Both are reads, both are in the service allowlist the build enforces, and both
// are answered by every OBD-II car sold since the mandate.
//
// WHAT THIS DOES NOT DO
//
// It does not change what gets polled. The sampler still asks for the Nexon PID
// set and an unsupported reading still comes back absent - it is now labelled
// absent-because-unsupported instead of absent-because-silent, which is the whole
// difference between a dashboard that is broken and one that is honest. Adapting
// the batches to the car in front of it needs a vehicle-profile format, and
// designing that against a sample of one car is designing it blind.
//
// WHY THE BACKUP NEEDS THIS
//
// A restore writes /didmap.csv, and that file is 214 verdicts about one specific
// engine. Restored onto a different car it would not fail - it would attach,
// silently, and every conclusion drawn from it afterwards would be wrong. So a
// backup carries vehKey() and a restore refuses on a mismatch. The key is a hash,
// not the VIN: the whole point is comparing two backups, which a hash does exactly
// as well, and a hash is not the vehicle identifier of a real car sitting in a
// file that is meant to be copied around.
//
// Everything here is pure - no bus, no filesystem, no clock - so the parsers are
// compiled and exercised by the host suite rather than by driving somewhere.

static const uint8_t VEH_VIN_LEN = 17;   // ISO 3779
static const uint8_t VEH_CAL_LEN = 16;   // SAE J1979, one calibration id
static const uint8_t VEH_CVN_LEN = 4;    // calibration verification number, binary

// The mode 01 support bitmaps, one per 32-PID block. 0x00 covers PIDs 01-20,
// 0x20 covers 21-40, and so on to 0xE0. Eight blocks is the whole of mode 01.
static const uint8_t VEH_BLOCKS = 8;

struct Vehicle {
  char vin[VEH_VIN_LEN + 1] = {0};
  char cal[VEH_CAL_LEN + 1] = {0};
  char cvn[VEH_CVN_LEN * 2 + 1] = {0};   // hex, because a CVN is not text

  uint8_t m01[VEH_BLOCKS][4] = {{0}};    // mode 01 support, per block
  bool    m01Have[VEH_BLOCKS] = {false};
  uint8_t m09[4] = {0};                  // mode 09 support, PIDs 01-20
  bool    m09Have = false;

  // Set when the ECU answered "not supported" rather than not answering. The
  // distinction is the same one the sweep and mode 06 discovery already make, and
  // it is the difference between "this car has no VIN over OBD" and "the ignition
  // is off". Absent data must never satisfy a rule.
  bool vinRefused = false;
  bool calRefused = false;

  // Did a second ECU answer? The sketch knows two responder ids - the engine
  // controller and the transmission - and only ever addresses the first.
  //
  // Answered-or-refused means present. Silence does NOT mean absent: an ECU that
  // is not fitted and an ECU that is not talking yet are the same thing on a CAN
  // bus, and there is no frame that distinguishes them. So this stays false until
  // something replies, and the page has to say "did not answer" rather than
  // "not fitted" - which is the honest reading and also the useful one, because
  // the usual cause is that the walk ran before the car was properly awake.
  bool tcmSeen = false;
  bool tcmAsked = false;
};

// ---------------------------------------------------------------- support masks

// A support reply: `41 <base> b0 b1 b2 b3` for mode 01, `49 00 ...` for mode 09.
//
// The echoed pid is checked, not assumed. A reply to the previous request arriving
// late is the ordinary failure on this adapter, and writing the 0x20 block's bitmap
// into the 0x00 block's slot would report a car supporting PIDs it has never heard
// of - which is worse than reporting none, because the tiles would then be blamed
// on the car rather than on the read.
static bool vehMaskParse(const uint8_t *buf, int len, uint8_t mode,
                         uint8_t base, uint8_t *out4) {
  if (!buf || len < 6 || !out4) return false;
  if (buf[0] != (uint8_t)(mode + 0x40)) return false;
  if (buf[1] != base) return false;
  for (uint8_t i = 0; i < 4; i++) out4[i] = buf[2 + i];
  return true;
}

// Is `pid` supported, according to the bitmap for the block starting at `base`?
//
// The bitmap is big-endian by bit: the most significant bit of the first byte is
// base+1, and the least significant bit of the fourth byte is base+0x20.
static bool vehMaskHas(const uint8_t *m, uint8_t base, uint8_t pid) {
  if (!m) return false;
  if (pid <= base) return false;
  uint16_t off = (uint16_t)pid - (uint16_t)base;
  if (off > 32) return false;
  uint8_t idx = (uint8_t)(off - 1);
  return (m[idx / 8] >> (7 - (idx % 8))) & 1;
}

// The last bit of each bitmap is not a PID, it is "there is another block after
// this one". A car that stops at 0x20 leaves it clear, and walking on regardless
// wastes four more timeouts per pass on an ECU that has already said no.
static bool vehMaskMore(const uint8_t *m, uint8_t base) {
  if (base >= 0xE0) return false;          // no block after 0xE0; +0x20 would wrap
  return vehMaskHas(m, base, (uint8_t)(base + 0x20));
}

/** The base of block `i`: 0x00, 0x20, ... 0xE0. */
static uint8_t vehBlockBase(uint8_t i) { return (uint8_t)(i * 0x20); }

/** Which block a PID falls in, or 0xFF for one that is in none (0x00 itself). */
static uint8_t vehBlockOf(uint8_t pid) {
  if (pid == 0x00) return 0xFF;
  return (uint8_t)((pid - 1) / 0x20);
}

// Does this car support this live PID, given everything discovered so far?
//
// Unknown is not unsupported. A block whose bitmap never arrived returns false for
// `supported` and true for `unknown`, and the caller has to say which - the
// dashboard's honest answer for an unread block is "not asked yet", never "your car
// cannot do this".
static bool vehPidSupported(const Vehicle &v, uint8_t pid, bool *unknown = nullptr) {
  uint8_t b = vehBlockOf(pid);
  if (b >= VEH_BLOCKS) { if (unknown) *unknown = false; return false; }
  if (!v.m01Have[b])   { if (unknown) *unknown = true;  return false; }
  if (unknown) *unknown = false;
  return vehMaskHas(v.m01[b], vehBlockBase(b), pid);
}

// ---------------------------------------------------------------- mode 09 text
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

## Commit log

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2026-08-15 Stop partial polls from blanking the dashboard
    A mode-01 batch carries six PIDs, which is ~14 payload bytes, so every poll is a
    multi-frame ISO-TP exchange. Both transports returned however many bytes had
    arrived when one timed out, which is indistinguishable from a complete short
    reply, so pollBatch parsed it and applied half a batch. The PIDs that never
    arrived stayed NAN, /data serialised them as null, and the dashboard rendered
    em-dashes over readings that were fine a moment earlier.
    That is why speed could sit there updating while throttle, load and coolant --
    the same batch -- read as blank.
    Transport:
    - canIsoTp/bleIsoTp return -3 for a reassembly that started but never finished,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
    [NexonOBD.ino]
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2026-08-15 v1.0.0: version stamp, persistent trend history, stop the status flicker
    Status flicker
    --------------
    The header alternated between "live" and "no response from ECU" about once a
    second. Two causes, one in each layer.
    canFlush() drained the RX queue once and returned immediately. A request that
    timed out mid-reassembly leaves its consecutive frames still in flight, so they
    landed inside the *next* request's read loop, where a stale CF with the wrong
    sequence number killed a perfectly good exchange - one failed poll turning into a
    run of them. It now drains until the bus has actually been quiet for 4 ms.
    The client also treated a single failed poll as "the ECU is gone". The values were
    bei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
    [NexonOBD.ino]
2026-08-15 v1.0.1: show the version on every page, not just the dashboard
    The version was only legible on the dashboard. The rule that hides the header
    subtitle on narrow screens lives in the shared stylesheet, but the override that
    countered it had been added to dashboard_html.h alone - so on a phone /scan and
    /update showed no version at all.
    /update is the page where it actually matters: the version there is the only way to
    confirm an upload took, and it was hidden on the device doing the uploading.
    Fixed in ui_css.h, where it should have been, so all three pages inherit it. The
    subtitle now hides only below 360 px, where there is genuinely no room.
    Also corrected the /update instructions, which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
    [ui_css.h]
2026-08-15 v1.0.2: fix the BLE dashboard going blank at 0.3 Hz
    Two mistakes of mine compounding on the BLE transport.
    ATST vs the read window
    -----------------------
    elm_ble.h initialised the adapter with ATST FF - 255 x 4 ms = 1020 ms - while
    pollBatch read with a 900 ms timeout. The adapter's own patience was therefore
    *longer* than ours, so on any slow reply the firmware stopped listening while the
    ELM was still waiting on the ECU. What came back had no '>' prompt, which is a
    truncated reply by definition.
    ATST is now 0x64 (400 ms) against a 1200 ms read window, so the adapter always
    answers - even if the answer is NO DATA - before the read gives up. The DID
    scanner's BLE window had the same inver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
    [NexonOBD.ino]
2026-08-15 v1.1.0: poll on the board, not in the request handler
    Switching pages was slow
    ------------------------
    handleData() polled the ECU inline: three batched requests, each up to two attempts
    at 1200 ms on BLE. The web server is single threaded, so a tap on "DID scanner"
    queued behind however long that took.
    Polling now runs in loop() as a rotating sampler - one batch per turn - publishing
    the newest sample to a cache that /data returns immediately. Nothing waits on the
    bus to serve a page. One batch per turn rather than three is the point: the server
    gets a turn between batches instead of after all of them.
    Scanning made it far worse. scanStep took a fixed count of 40 identifiers, which is
    ab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
    [NexonOBD.ino]
2026-08-15 v1.2.0: raise the read rate on BLE
    Three changes, in descending order of how much they are likely to matter.
    Publish after every batch, not after three
    ------------------------------------------
    A sample needed all three batched requests before anything reached the page, so the
    update rate was a third of the bus transaction rate. Each batch now publishes, with
    the other two carried forward from a per-batch cache while they are still fresh.
    Carrying values forward is only safe with a bound on it, so a batch older than 3 s
    is dropped to NAN rather than published as current - otherwise this would be the
    original blanking bug inverted, showing a stale number as live. The cache holds the
    verifi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
    [NexonOBD.ino]
2026-08-15 v1.2.1: fix scan progress never being reported, share the bus during a scan
    Scan progress was unreachable
    -----------------------------
    /data emitted scan progress and the active transport only on the ok:true branch -
    which is exactly the branch that cannot be taken while a scan is running, because
    the sampler pauses and the sample goes stale within four seconds. The result was a
    progress bar pinned at 0 % for an entire sweep and a header transport reading as an
    em-dash. Both are now emitted on either branch.
    Freezing the dashboard for a whole sweep was the wrong trade
    ------------------------------------------------------------
    A full 0000-FFFF pass is over half an hour on CAN and the bett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
    [NexonOBD.ino]
2026-08-15 v1.2.2: stop b2/b3 expiring before their next turn
    "All values" kept blanking twelve of its twenty rows on BLE, and the cause was
    arithmetic I got wrong in v1.2.0.
    SAMPLE_ORDER is {b1, b2, b1, b3}, so b2 and b3 are polled once every four batches -
    but SAMPLE_STALE_MS was hard-coded to 3 s. That only holds if a batch completes in
    under 750 ms. Over BLE a batch is comfortably longer, so at ~800 ms the cycle is
    3.2 s and both batches expired before their next turn, every cycle. The affected
    fields are exactly b2 (oil, IAT, voltage, both trims, fuel rate) and b3 (lambda,
    catalyst, timing, run time, ambient, fuel level) - twelve rows.
    The window is now derived from the measured cycle: three ful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
    [NexonOBD.ino]
2026-08-15 v1.2.3: scanner controls reflect the scan
    Start stayed enabled and still read "Start scan" while a sweep was running. That is
    not cosmetic: handleScanStart resets cur, tried and negatives and calls
    hits.clear(), and none of it is persisted anywhere - so a stray tap on a button
    that looked available silently discarded the whole run.
    Start is now disabled and reads "Scanning...", Stop is enabled only while there is
    something to stop, CSV only when there are hits to export, and the ECU and range
    inputs are locked for the duration since changing them mid-sweep does nothing.
    Disabled inputs are dimmed, or a locked control reads as unresponsive rather than
    deliberately unavailable.
    The page also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
    [ui_css.h]
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2026-08-15 v1.2.5: back off progressively when re-picking the transport
    The adapter is powered from the OBD port and stays alive with the car switched off,
    while the board runs from the accessory socket and does not. Every start therefore
    meets an ELM327 that may still be holding the BLE link to a board that vanished
    without ever disconnecting, so the first connect can fail for a reason that clears
    itself within seconds.
    The retry gate was a flat 15 s of silence plus 20 s between attempts, with lastPick
    starting at zero - so a failed first connect meant no data at all until 20 s after
    boot, then 40, at every ignition. bleIsoTp returns immediately while disconnected,
    so the dashboard has nothing to sho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
    [NexonOBD.ino]
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2026-08-15 v1.5.0: read the mode 06 on-board monitors
    FINDINGS recorded mode 06 as supported - 46 00 C0000001 - and never explored. It is
    the ECU's own test results: what each monitor measured and the limits it judges that
    against. Worth more than /dtc, because a fault code only appears once something has
    already failed, whereas this shows how much room is left.
    Pass and headroom do not require knowing the units, which is what makes the page
    honest. A test passes when its value sits inside its own limits, and the headroom is
    a fraction of that window - both unit-free and always correct. The unit-and-scaling
    table is long and only partly documented, so values are shown raw with their scaling
    id and dec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
    [NexonOBD.ino]
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2026-08-15 v1.7.0: per-drive CSV logs, and scans that survive the ignition
    Trip logs
    ---------
    A CSV row a second while the ECU answers, to the 1.5 MB filesystem partition that
    has been sitting unused since the board was chosen. Twenty-two columns with
    wall-clock time and uptime on each row, and empty cells rather than zeros where a
    value was not read - a gap has to stay a gap, not become a reading of nought.
    The column list is declared once, as names paired with pointers-to-member, so the
    header cannot drift from the rows underneath it.
    LittleFS rather than SPIFFS: this board loses power the instant the ignition goes
    off, mid-write as often as not, and LittleFS is copy-on-write with no in-place
    meta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
    [NexonOBD.ino]
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2026-08-16 Serve a frontend bundle off LittleFS, and stop rotation eating /scanhits.csv
    Phase 0 - a bug found while planning
    ------------------------------------
    Everything that walked the filesystem root matched any name containing ".csv".
    Rotation deletes the lexicographically smallest match when space runs short, and
    "/scanhits.csv" sorts before "/t0001.csv" - so a long drive silently deleted the
    DID sweep's results and its resume position to make room for another minute of
    logging. The same looseness made the sweep's hits appear on the trips page as a
    trip, downloadable and deletable, and counted in the storage figures.
    trip_names.h now decides what a trip log is, in one place, and everything that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
    [NexonOBD.ino]
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2026-08-16 Declare the /data contract, and serve the bundle at / when one is installed
    The firmware emits 28 field names in handleData(); the frontend reads them by
    name. Nothing checked they agreed, because nothing had to - both lived in one
    build, so a rename broke loudly. The frontend is moving to its own build and its
    own deploy, which turns that into a silent failure: a blank gauge in the car and
    a green suite on the bench.
    contract/data.json declares the contract once. firmware/test checks it against
    handleData() in both directions - a field the firmware quietly stopped sending
    is as much a break as one the contract never knew about - and rejects duplicate
    keys, which would otherwise mean the sa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
    [NexonOBD.ino]
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2026-08-16 Phase 4: delete the pages that moved into the bundle
    dashboard_html.h, scan_html.h, mon_html.h, trip_html.h and watch_html.h are
    gone. Their UI is the bundle's now, and keeping a second copy in flash would
    mean two frontends drifting apart - which is the duplication this whole move
    exists to end.
    Three pages stay in flash, each because it must not depend on the bundle:
    /update OTA flashing, the recovery path of last resort
    /ui bundle management, what you reach when a deploy went wrong
    / boot_html.h, the fallback below
    boot_html.h is deliberately not a second dashboard. It is a floor: speed, rpm,
    coolant, battery, whether the ECU is answering, and a route to the two pages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
    [NexonOBD.ino]
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2026-08-29 v1.11.3: two board-only bugs in the bundle serving path (#5)
    * v1.11.2: choose the stored name, do not trust the uploaded one
    Seen on the car: the bundle uploaded cleanly, the /ui page listed
    index-1.11.1.html.gz, and the board reported "no frontend installed" over the top
    of it. The phone had renamed the download, and uiInstalled() looks for the entry
    point by name.
    The upload used the multipart filename as the target, which is a name the client
    picks. Phones rename downloads routinely - a version suffix, a "(1)" for a
    duplicate - and a name like "index (1).html.gz" would not even have been stored,
    since uiPathOk refuses spaces and brackets.
    The build emits exactly one HTML file, so any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
    [NexonOBD.ino]
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2026-08-29 Bound the single-frame transmit, and make read-only a tested property
    canIsoTp built its request as `uint8_t frame[8]; frame[0] = plen;
    memcpy(&frame[1], payload, plen);` with nothing checking plen. A single frame
    is one PCI byte and seven of payload, and the largest caller in the tree -
    the mode 01 batch, six PIDs plus the mode byte - passes exactly 7. At the
    limit with nothing spare. A seventh PID in a batch, or packing two DIDs into
    one 0x22 request to get the obvious 3x throughput win, writes past the frame
    on the stack and nothing says so.
    Latent today, so this is not a fix for an observed failure - it is removing
    the reason the next reasonable change would be one. obdIsoTp states the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
    [NexonOBD.ino]
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2026-08-29 v1.12.0: a battery floor under the idle timer, and boot forensics
    The idle timer answers "the car is off". It does not answer "the battery is
    going flat", and the two come apart exactly where it matters: an ECU that
    keeps answering with the engine stopped - ignition on at the roadside, a long
    session parked, a module that stays awake - resets lastEcuOkMs on every
    reply, so the ten-minute guard never arms and the board draws from a battery
    nothing is charging for as long as that lasts.
    Below 11.8 V for thirty continuous seconds with the engine stopped, it shuts
    down. A lead-acid battery at rest sits near 12.6 V; 11.8 V is roughly a
    quarter charged and about where a cold start stops being a c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
    [NexonOBD.ino]
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2026-08-29 Rename to Obdurate
    ob·du·rate — adj. unyielding; refusing to be moved. It contains OBD, and it
    says the design stance: this firmware sends 0x01, 0x03, 0x06 and 0x22, all
    reads, and the build fails if that ever changes.
    NexonOBD named the project after one car, which is a ceiling rather than a
    name. Nobody with a different car adopts a tool called after someone else's,
    and the parts that are actually generic - ISO-TP, both transports, the
    recorder, the scanner, the staleness and honesty rules - are most of the
    tree. The car-specific parts are the PID lists, the ECU addresses, the bus
    timing and the warning thresholds, and the README now says so plainly instead
    of implying the whole thing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
    [Obdurate.ino]
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2026-08-29 Compile, flash and verify on hardware - and write down how
    Everything now runs on a real board. Three things had to be fixed to get
    there, all of which would have cost the next person the same hour.
    build.sh had no Windows case. Git Bash reports MINGW64_NT-..., which fell
    through the catch-all to Linux_64bit, so it downloaded a Linux ELF that
    unpacks perfectly and then fails at first use with "cannot execute binary
    file: Exec format error" - an error pointing nowhere near the cause. Windows
    ships as a .zip rather than a .tar.gz, extracted with python3 because Git Bash
    has no unzip and python3 is already a dependency of the host tests. A version
    probe right after install now fails at the poi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
    [Obdurate.ino]
2026-08-29 Phone-first redesign, and a screen for reading a drive back
    The dashboard is used one-handed on a phone wedged in a car, and every tab
    lived in a scrolling strip at the top of the screen - the furthest point on a
    handset from the thumb holding it. The nav moves to a fixed bar at the bottom,
    the palette becomes translucent plates on a lit ground, and the rpm dial and
    the speed tile merge into one instrument: a 180 degree sweep with the speed
    numeral inside it.
    Token and class names are unchanged throughout. They are referenced from JSX as
    well as from CSS - Spark.jsx takes its stroke as a var(--aqua) string handed
    over by the call site, and live/status.js, watch/status.js and flags.js emit
    '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
    [ui_css.h]
2026-08-29 v1.13.0: home-screen install, and a sweep's results that outlive the sweep
    Two things, one of them a bug with the same shape as the trip recorder.
    scanLoadHits() sat after scanBegin()'s early return, so hits came back from
    flash only while a sweep was mid-run. A sweep that finished - or was stopped,
    which is how most of them end - left /scanhits.csv on the filesystem with
    nothing ever reading it. /watch offered an empty picker on a board holding
    every identifier a sweep had found, and the documented route from "this
    identifier answers" to "this identifier is coolant" was unreachable except in
    the one state where you would not want to start watching anyway.
    Found by looking at the board: it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
    [Obdurate.ino]
2026-08-29 Put the ground back under the glass
    The plates are translucent white. On a flat fill they are grey boxes, and the
    layering the whole direction rests on does not read at all - which is what the
    port shipped, because the two light sources behind them were in the prototype
    and never made it into the stylesheet.
    Two soft radials, fixed to the viewport rather than painted into the document,
    so the light stays where it is while a long page scrolls under it. A
    pseudo-element rather than background-attachment:fixed, which iOS Safari either
    ignores or repaints on every scroll frame, and pointer-events:none so it can
    never swallow a tap. .wrap is raised over it; the header and the tab bar
    already car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
    [ui_css.h]
2026-08-29 Stop the header covering the light it sits in front of
    The lit ground went in, and then the header hid it. header carries its own
    rgba(7,7,11,.92) fill at z-index 5, which is a near-opaque slab laid over the
    fixed glow layer - and the brighter of the two sources is centred at the top
    right, directly behind that bar. So the one band of the screen where the light
    was strongest was the one place it never showed.
    The fill drops to .58, but only inside the @supports block, where there is a
    backdrop-filter to keep the text legible. The opaque value stays as the
    fallback: without a blur, cards scrolling under a see-through header are
    unreadable, which is a worse bug than the one being fixed.
    Both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
    [ui_css.h]
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2026-08-29 Let the light through the tab bar too
    Same defect as the header, same fix. nav carried rgba(18,18,24,.86)
    unconditionally, and the second light source is centred at the lower left -
    directly behind the bar - so an opaque fill there hid one of the two sources
    outright.
    The fill moves into the @supports block at .62 with the opaque value left as
    the no-blur fallback, and the blur goes to 18px rather than the header's 16:
    content scrolls directly under this one, and its labels are 8.5px where the
    header's title is 16.
    Both halves of the shared sheet move together, byte for byte.
    [ui_css.h]
2026-08-29 Triage gets buttons, a timer and a progress bar
    It was two curl URLs and a serial log. Now it is a panel on the Scanner page,
    under the sweep that produces the identifiers it re-reads - rather than a
    seventh nav tab, which at six across on a phone is a tab you tap wrong.
    Start, Stop, a progress bar, the counts, and a clock. The clock comes from the
    board, not the page: triage is driven by the board and can be started from
    another phone or before this tab was opened, so a client-side timer would
    restart every time the page was reopened - which is exactly when you want to
    know how long it has been going. Re-pressing Start on a run already going does
    not reset it either.
    Progress is measured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
    [Obdurate.ino]
2026-08-29 A triage run survives the ignition
    triageOn was a plain static, so a power cycle silently disarmed it. The sweep
    has always persisted its own run flag and resumes on the next boot; triage not
    doing the same meant a board carried out to a car came up with the register
    loaded and triage quietly off - and every restart during a drive stopped it
    without saying so, which is the one situation the feature exists for.
    One bool in NVS, written only when it changes. Restored at boot, and only when
    there is a register to resume into.
    Host suite 343 + 222 + 34, all 0 failed. NOT yet flashed to the board.
    Claude-Session: https://claude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
    [Obdurate.ino]
2026-08-29 Fix a string literal I pushed broken, and lint for the whole class
    f55c951 does not compile. The resume message lost its newline escape to a
    text-munging script and became a string split across two lines, and I pushed
    it after a green host suite without ever running the compiler.
    That is the real defect, and it is structural rather than careless. Nothing in
    the host suite parses the sketch as C++: extract.py pulls named functions and
    compiles those, so setup(), the handlers and the periodic tasks are only ever
    read as text. A broken literal there passes all 230 source assertions and
    surfaces at arduino-cli, which needs a 6 GB toolchain and is the slowest and
    furthest place from the mistake.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
    [Obdurate.ino]
2026-08-29 Endpoints to take the data off the board, put it back, and clear it
    A sweep of the identifier space is over half an hour on CAN and the better
    part of a day over BLE, the register behind it takes drives to build, and the
    trip logs are the drives themselves. All of it lives on a 1.5 MB partition
    inside a device that gets unplugged, reflashed and left in a hot car, and
    until now there was no way to get any of it off except one trip file at a
    time.
    /files lists the data files with sizes and the free space, /file streams one,
    /file/put writes one back, /reset clears them.
    The backup itself is assembled in the BROWSER, not here, and these endpoints
    are shaped for that. The board has one thread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
    [Obdurate.ino]
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2026-08-29 Ask the car what it is, and what it can answer
    Discovery, not adaptation. The sampler still asks for the Nexon PID set and an
    unsupported reading still comes back absent - it is now labelled
    absent-because-unsupported rather than absent-because-silent, which is the whole
    difference between a dashboard that is broken and one that is honest. Adapting
    the batches at runtime needs a vehicle-profile format, and designing that against
    a sample of one car is designing it blind.
    Twelve questions, once per boot: the mode 01 support bitmaps block by block, then
    mode 09 for the VIN, the calibration id and its checksum, then one probe at the
    transmission's responder id. vehicle.h holds the parsers, all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
    [Obdurate.ino, vehicle.h]
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2026-08-30 v1.17.0: the board runs the whole investigation, and belongs to one car
    Two features that turned out to be the same feature.
    AUTOPILOT
    Sweep, triage and watch were three buttons pressed in order, hours apart, with the
    fitting done afterwards in a spreadsheet. Nobody chooses differently at any of those
    points - which is what makes it automatable - and each phase outlasts anyone's
    attention, so a prompt between them is one that gets missed and a pipeline that
    stalls until somebody happens to open the page.
    Started once, it now advances on its own and keeps its phase in NVS, because the
    ignition going off is a power cut and this pipeline is measured in drives: about
    30 minutes for a sweep, a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
    [Obdurate.ino]
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
